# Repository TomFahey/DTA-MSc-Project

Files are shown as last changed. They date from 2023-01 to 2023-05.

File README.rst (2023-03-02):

DIY DTA
=======

Description
-----------

This project contains the assorted code and schematics used in the design of a low-cost Differential Thermal Analysis device. This design utilises off-the-shelf parts, in
conjunction with open source software, to provide a kit-based setup allowing users to explore basic application of the DTA technique, in an intuitive and low-cost manner.

Components
----------

The parts used in this design include:

* Raspberry Pi 4 Model B, running RaspbianOS (Buster)
* Raspberrry Pi Pico microcontroller
* Adafruit MAX31865 and MAX31856 temperature sensing breakout boards
* T-type thermocouple
* RTD sensors
* Cytron HAT-MDD10 motor controller board
* Adjustable DC Power Supply
* Custom PCB boards

Structure
---------

The repository consists of three main parts:

1. The webapp folder contains the python code and .ipynb notebooks which implement the widget-based user interface. This is intended to be run on a small board computer (SBC), such as a Raspberry Pi Model B (preferably running Raspbian OS), using the JupyterLab web-based interactive development environment. voila-dashboard, is used as a server extension within Jupyter, for deployment as a standalone web application.
2. The microcontroller folder contains the python code to be run on a CircuitPython compatible microcontroller (Raspberry Pi Pico), which interfaces with the SBC via USB.
3. The pcb folder contains the Autodesk Eagle files for the PCBs used by the system.

Documentation
-------------

The documentation for this project is available at `DIY-DTA <https://tomfahey.github.io/DTA-MSc-Project/>`_

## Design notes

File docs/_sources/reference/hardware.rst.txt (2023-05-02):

Hardware reference
==================

.. _ref_hardware_overview:

Overview
--------

A top-down overview of the system, indicating the respective roles of the 
components, is shown below:

.. figure:: ../images/HardwareDetailView.png
   :align: center
   :scale: 50%
   :alt: Microcontroller software block diagram

The *left* side of the diagram shows the components associated with high-level
system functions, such as:

* Displaying information and receiving user input 
* Defining heating programmes, based on user input and initiating/stopping
  these based on user commands
* Communicating with the microcontroller program, updating it with the 
  appropriate programed parameters and receiving sensor data sent by it.

The *right* side of the diagram shows the components associated with the low-level 
integration of electronics components and control processes, such as:

* Reading values from attached temperature sensors
* Regulating heat output of the thermoelectric module, based on parameters specified
  by the current heating programme, as well as the current temperature readings
* Communicating with the web app program running on the Raspberry Pi, sending
  temperature data as requested and receiving parameters related to the heating
  programme.

.. _ref_hardware_electronics:

Electronics
-----------

.. _ref_hardware_electronics_sensors:

Temperature Sensors
^^^^^^^^^^^^^^^^^^^

As previously shown in :doc:`components`, the temperature sensors that can be
used with the system include restistance temperature detectors (RTDs) or
thermocouples.

For absolute temperature measurements, the details of how RTDs and thermocouples
function, and their differences are not particularly important. In general, RTDs
will achieve greater precision, up to 0.1 degrees Celsius, compared to
thermocouples, which are typically limited to approximately 0.5 degrees Celsius
precision - however, these will be subject to the specific type of RTD/thermocouple
used.

However, in the case of differential temperature measurements, thermocouple
temperature sensors are able to provide a unique advantage over RTDs, due to
their ability to be wired in a 'differential' setup, as shown below:

.. figure:: ../images/DifferentialThermocouple.png
   :align: center
   :scale: 60%
   :alt: Thermocouple wiring

The voltage produced at the open terminals of the differentially wired thermocouple
is approximately proportional [#T-Type]_ to the difference in temperature between
the two probes [#Non-linearity]_ . For sufficiently high-resolution voltage sensors,
this can allow a differential thermocouple to achieve precision in the tens of
mK. 

Because the temperature-dependent voltage values produced by the sensors is typically
very small (in the mV, or less), the use of amplification, or high-resolution voltage
sensors (or both) is necessary to extract the temperature readings.

Unsurprisingly, integrated chips providing exactly these features are available, such
as Analog's MAX31865 (RTD) and MAX31856 (Thermocouple) products. These ICs both feature
high-resolution ADCs, precision voltage/current references, built-in amplification and
SPI communication, allowing them to be easily integrated with a microcontroller over
the SPI bus. 

The Adafruit breakout boards used for the system integrate these ICs, allowing any 
combination of up to 4 RTDs/Thermocouples to be used for temperature measurements.

.. _ref_hardware_electronics_actuators:

Temperature Actuators
^^^^^^^^^^^^^^^^^^^^^

The temperature control of the sample and reference is handled with the use of
a thermoelectric module (TEM). This is a type of solid state device, which acts 
like a heat pump, in response to an applied electrical current - heating on one
side, whilst cooling on the other. 

This heat pump effect can be reversed by reversing the direction of the electric 
curent, causing the previously heated side to cool and vice versa. This allows
TEMs to achieve very precise temperature control, by applying corrective
heating/cooling to an attached object, in order to maintain a target temperature.

In order to apply the reversible current needed to drive the TEM, an electronic
circuit called a H-Bridge is used, consisting of four switching transistors,
which selectively allow current to flow in one direction, or the opposing one,
based on the input applied to their control terminals (e.g voltage applied
to the gate terminal, in the case of MOSFET transistors).

.. figure:: ../images/HBridge.png
   :align: center
   :scale: 25%
   :alt: H Bridge
   
This type of circuit is often used to drive reversible electronic loads, such 
as brushless DC motors, or speakers - typically with the use of a pulse-width
modulated (PWM) signal to control the switching of the MOSFETs. These very
common usecases mean that existing implementations of H-Bridge circuits are
both plentiful and relatively cheap, allowing off-the-shelf parts, like the
HAT MDD10A to be used for our purposes.
   
Additional care is needed in the case of TEMs when it comes to PWM control,
however, due to issues such as thermal cylcing [#TE-Tech]_ and reduced
efficiency [#THERMICOOL]_ . For these reasons, a low-pass LC filter is used,
as shown below, to smooth the PWM output of the H-Bridge, which is present
on the 
:ref:`Thermoelectric module interface board <_start_components_custom_tem_board>`.

.. figure:: ../images/ClassDAmp.png
   :align: center
   :scale: 25%
   :alt: Class D Amplifier

.. rubric:: Footnotes

.. [#T-Type] `NIST Temperature-Voltage chart for T-type thermocouple
      <https://srdata.nist.gov/its90/download/type_t.tab>`_
.. [#Non-linearity] In practice, the non-linearity in the temperature-voltage
      relationship is accounted for either by use of the Callendar-Van Dusen
      equation, or interpolation of a lookup table.
.. [#TE-TECH] `TE-Tech Technical Information <https://tetech.com/faqs/#11>`_
.. [#THERMICOOL] `Active Thermoelectric Cooling Solutions for Airspace 
      Applications: the THERMICOOL Project
      <https://ieeexplore.ieee.org/stamp/stamp.jsp?tp=&arnumber=7862124>`_

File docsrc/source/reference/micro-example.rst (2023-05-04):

Microcontroller software example
================================

.. role:: pyc(code)
   :language: python
   :class: highlight

.. _ref_micro_example:

This document describes a stripped-down version of the python code developed
for the DTA system, intended to provide a more easy to follow demonstration
of the underlying processes going on in the full implementation.

The stripped-down version of the code is (mostly) contained within a single file,
main.py, which carries out an approximately equivalent routine to the
full microcontroller code, without the use of programming abstractions
such as separate classes and modules. 

Requirements
------------

In order to properly familiarise yourself with the effects of each
part of the code you will need the following items:

- A Raspberry Pi Pico, with headers attached, running CircuitPython (7.3.3,
  preferably). Instructions on how to install CircuitPython 
  `here <https://learn.adafruit.com/welcome-to-circuitpython/installing-circuitpython>`_.
- A Windows or Linux computer, with the Python editor 
  `Thonny <https://thonny.org/>`_  installed. Also needed is a serial client
  application. `PuTTY <https://www.putty.org/>`_, available on both Windows
  and Linux, is an excellent choice for this and is the client used in this
  tutorial. 
- A Micro USB cable to attach the Pico to the computer
- At least one `Adafruit MAX31865 RTD amplifier <https://www.adafruit.com/product/3328>`_ 
  breakout board and an accompanying RTD temperature sensor
- At least one `Adafruit MAX31856 Thermocouple amplifier <https://www.adafruit.com/product/3263>`_ 
  breakout board and an accompanying thermocouple temperature sensor
- For proper demonstration of temperature control, a thermoelectric module
  (TEM), DC power supply and 
  `HAT-MDD10A <https://www.cytron.io/p-10amp-6v-24v-dc-motor-driver-hat-for-rpi-2-channels>`_ 
  H-Bridge motor controller are strongly recommended. 
- It is feasible to substitute the H-Bridge controller with an appropriately 
  spec'd high-side or low-side logic-level MOSFET (such as the FQP30N06L)
  using the PWM output of the MCU to control the MOSFET's gate terminal.
  However, if doing so, you **must** edit lines 435 and 437, making sure to
  set the value of both PWM pin's duty cycle to zero, when :pyc:`u<0`.
- Wires and preferably a small breadboard to connect everything

Hardware setup
--------------

With all of the necessary parts obtained, you will need to
connect the electronics according to the following diagram:

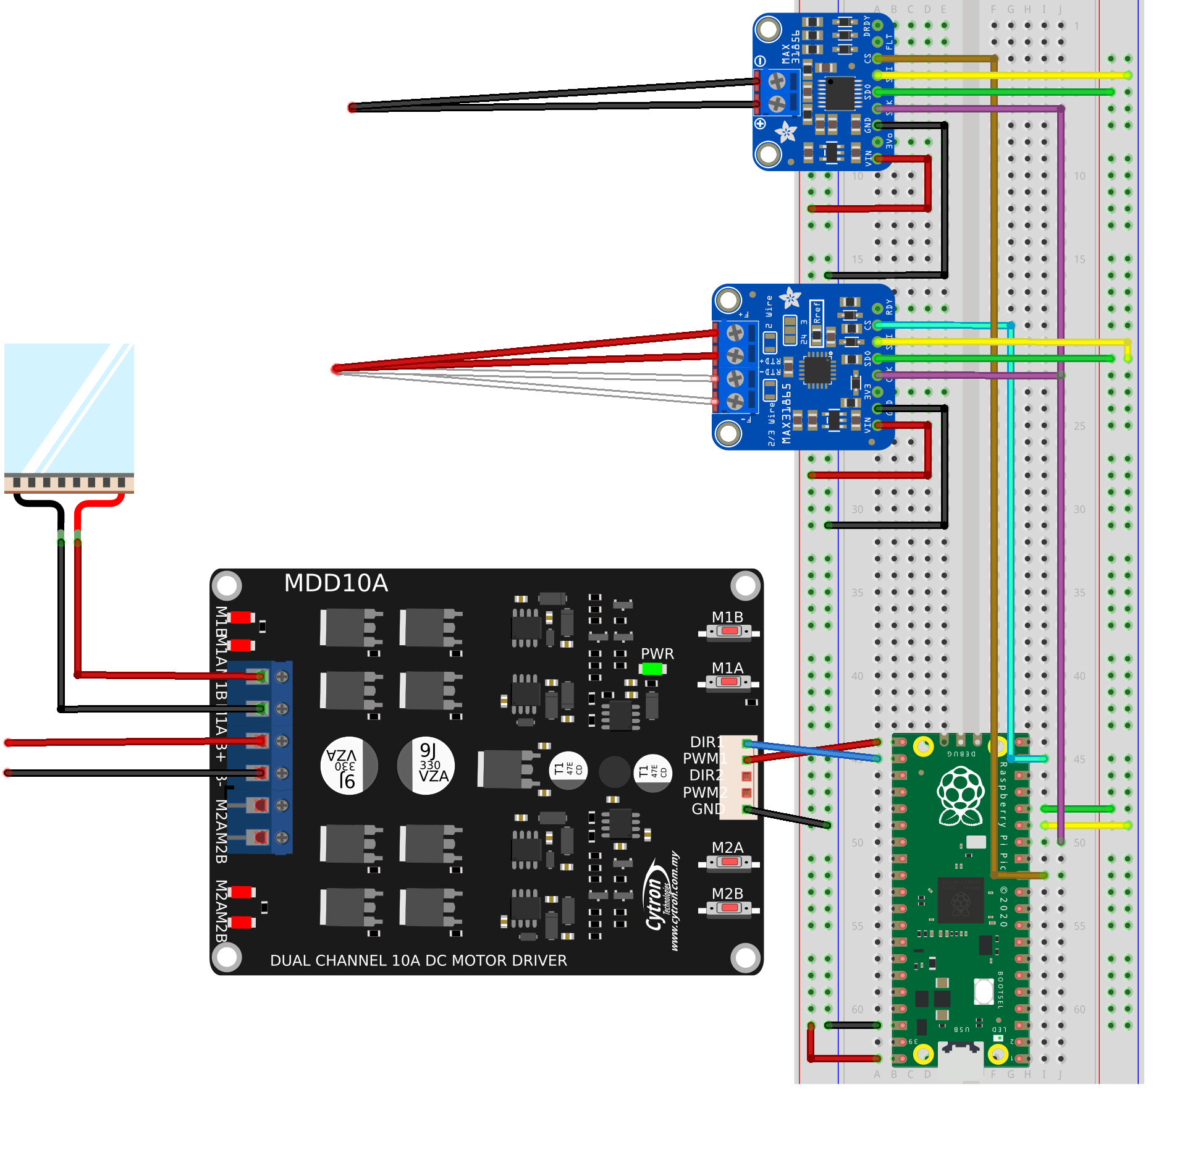
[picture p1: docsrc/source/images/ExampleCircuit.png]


The unconnected red and black wires on the left-hand side of the diagram
should be connected to the positive and negative connections of the DC
power supply, respectively.

For the purposes of demonstrating temperature and heat control, the
thermocouple and RTD sensors can simply be attached directly to one of
the faces of the thermoelectric module. We will want to attach it to the
side that gets hot (the other side will cool down), which depends on the
direction of the current that drives it.

You can test this yourself, by using the buttons marked M1B and M1A. These
buttons allow the H-Bridge to be manually controlled, with one button
providing forward current and the other reverse current.

Pressing down M1A, you should find that one side of the TEM heats up, whilst
the other side cools down. With M1B pressed down instead, you should find
the sides are now reversed i.e the previously hot side is now cold and the
previously cold side now hot etc.

For the MAX31865 amplifier board, you may need to short some of the solder
bridges arranged on the board, depending on the number of wires used for
your RTD sensor. You can find more information about this in the Adafruit
`online instructions <https://learn.adafruit.com/adafruit-max31865-rtd-pt100-amplifier/rtd-wiring-config>`_.

Software setup
--------------

With Thonny and a suitable serial communication application installed, you
should open Thonny up, which should look somewhat similar to the picture below:

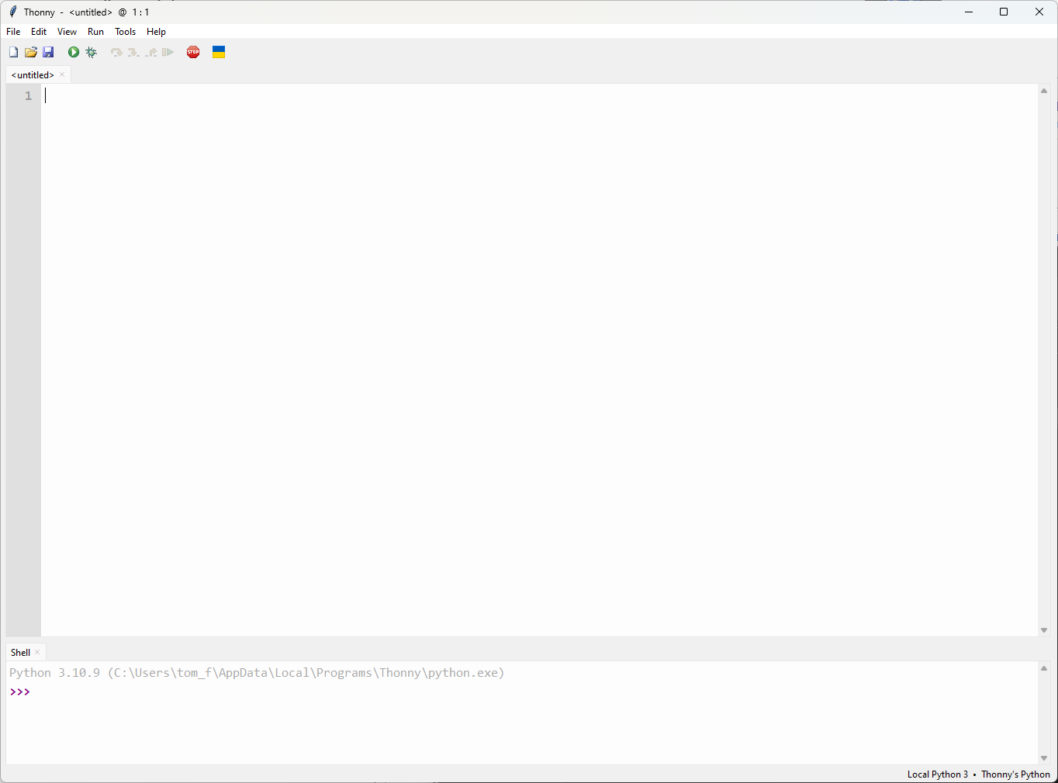
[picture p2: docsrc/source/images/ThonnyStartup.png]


We can see in the bottom right hand corner that the current *interpreter* is
configured to the local Python 3 installation on the computer. We therefore
need to change this to the CircuitPython interpreter, that is on the Pico.
With the Pico plugged into the computer via the USB connection, left-clicking
the interpreter in the bottom right-hand corner should result in the following
menu, from which you should select CircuitPython:

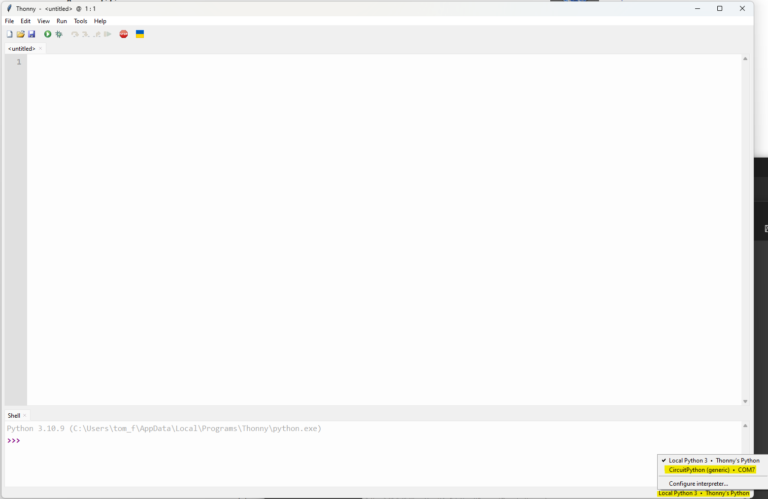
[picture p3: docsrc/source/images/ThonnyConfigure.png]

   
Next, we will want to configure the user interface, to show the necessary
elements. You can do this by clicking the "View" menu, making sure that the
highlighted options are selected:

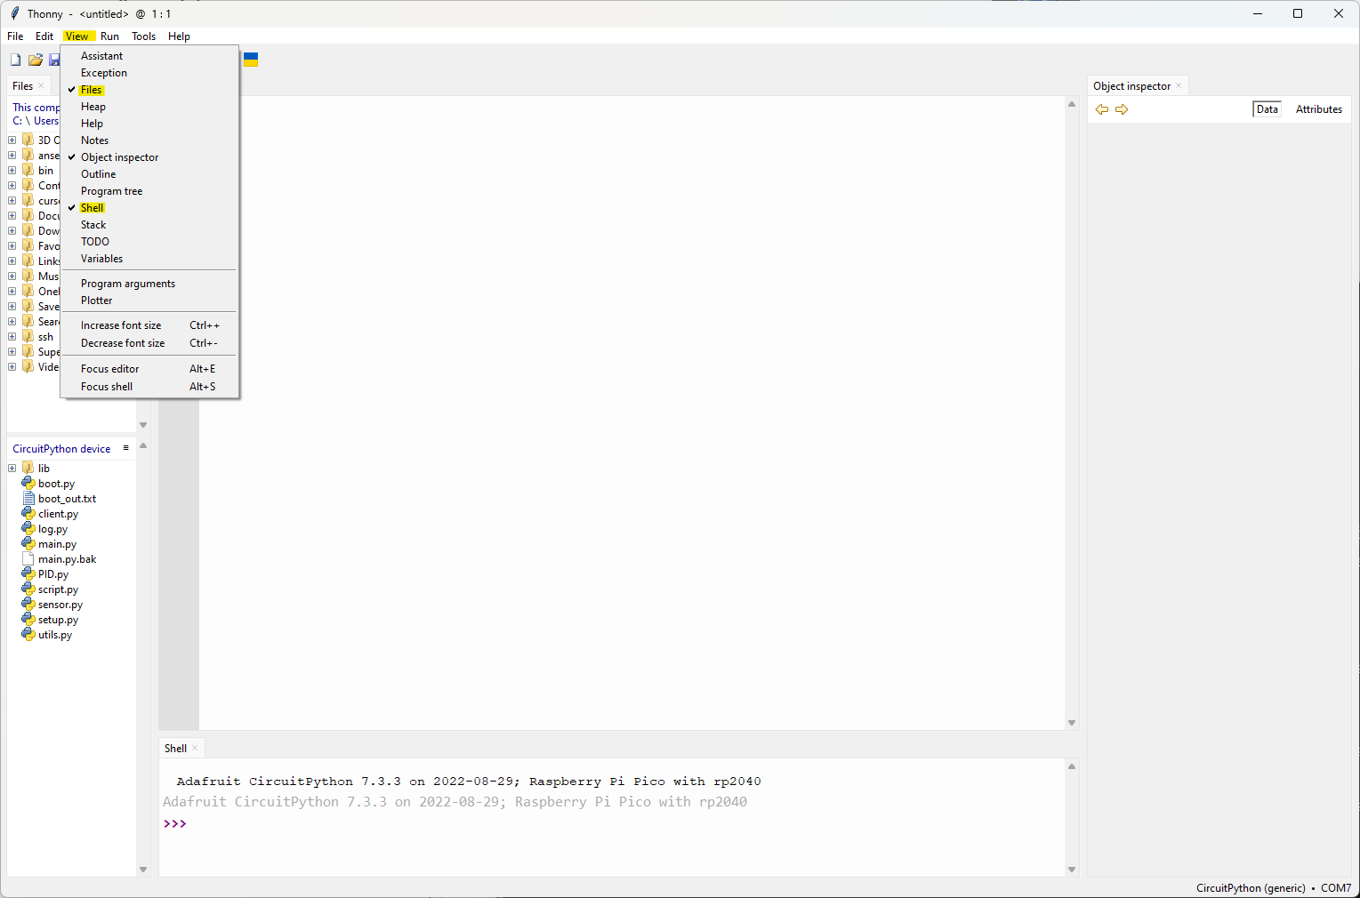
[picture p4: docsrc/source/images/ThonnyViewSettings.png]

   
You will probably notice that the Files menu shows two filesystems, namely
that of the local computer, as well as that of the microcontroller. In order
to install the python code used for this example, you will need to navigate
to where the files are stored on your own computer, from which you should
be able to copy them to the microcontroller by right-clicking on them as
shown below:

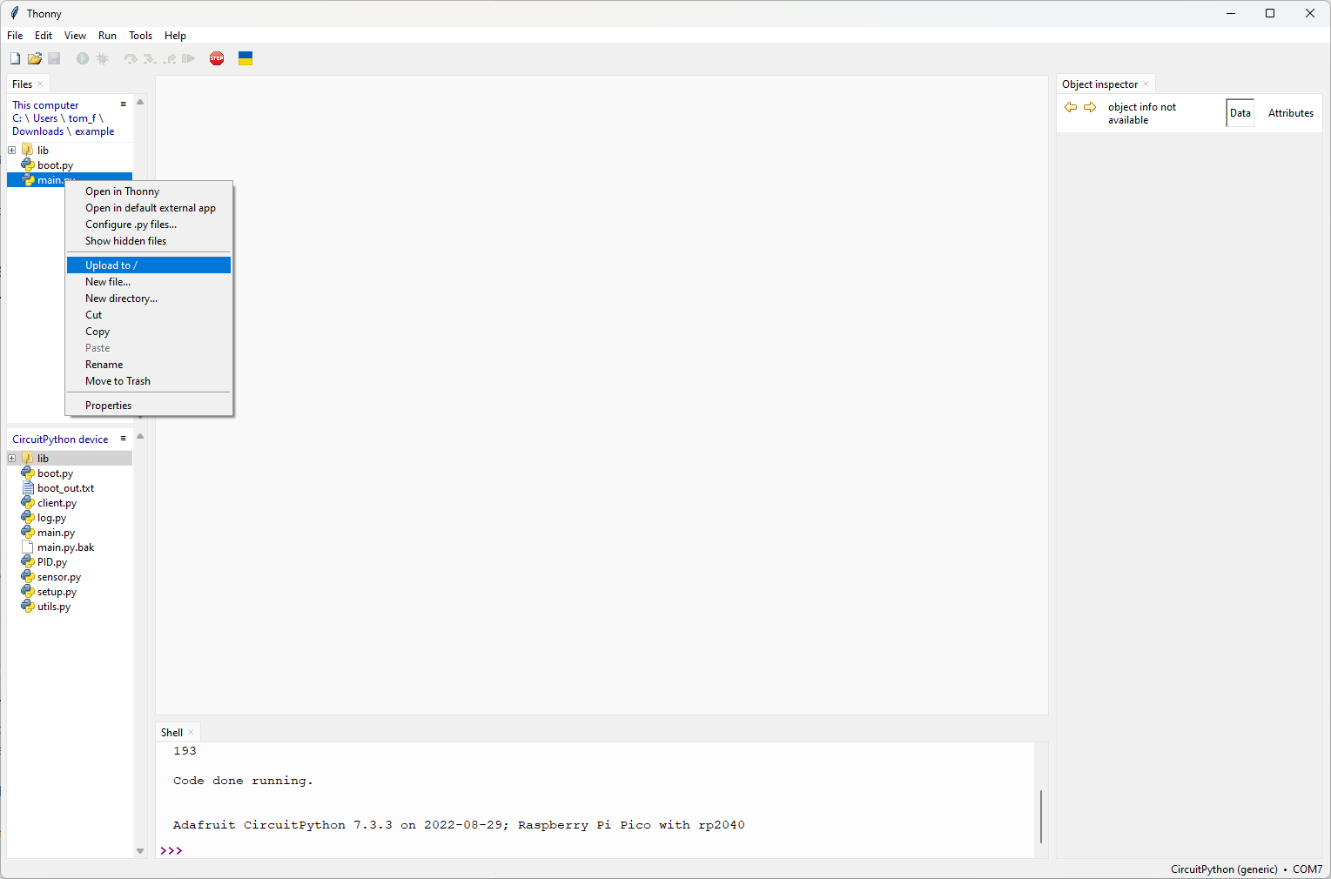
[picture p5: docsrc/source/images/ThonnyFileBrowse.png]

   
With the main.py and boot.py files, as well as the lib directory, copied to 
the Pico's filesystem, you can open the version of main.py installed on the
Pico by double clicking it.
   
Inspecting the program
----------------------

Upon opening main.py, you should see an approximately 450 line python
program, which has been divided into headered sections by the inline
comments.

The first 140 lines of code largely consist of boiler-plate code, such as
pin definitions, module imports and setting up periperhal devices.

Lines 10-13 import the basic interal Circuitpython libraries that are
required for measuring time, accessing board peripherals (like GPIO pins)
and buses such as the I2C, I2S, SPI, UART buses etc.

Lines 24-100 involve the initialising of the SPI devices, which in this
case, are the MAX31865 and '56 breakout boards. If you lookup a pinout
of the Pico, you will see that the pin definitions specified in lines 33-35
match the pins used in the wiring diagram shown earlier.

Between lines 52 to 100, the python objects used to model the two breakout boards
are initalised, :pyc:`max31865` and :pyc:`max31856`.

Temperature sensors
###################

We can get a better understanding of these objects by running the program and
inspecting them in the object inspector. Press the green "Run" button, to
run main.py and then type :pyc:`max31865` in shell prompt, hitting enter.

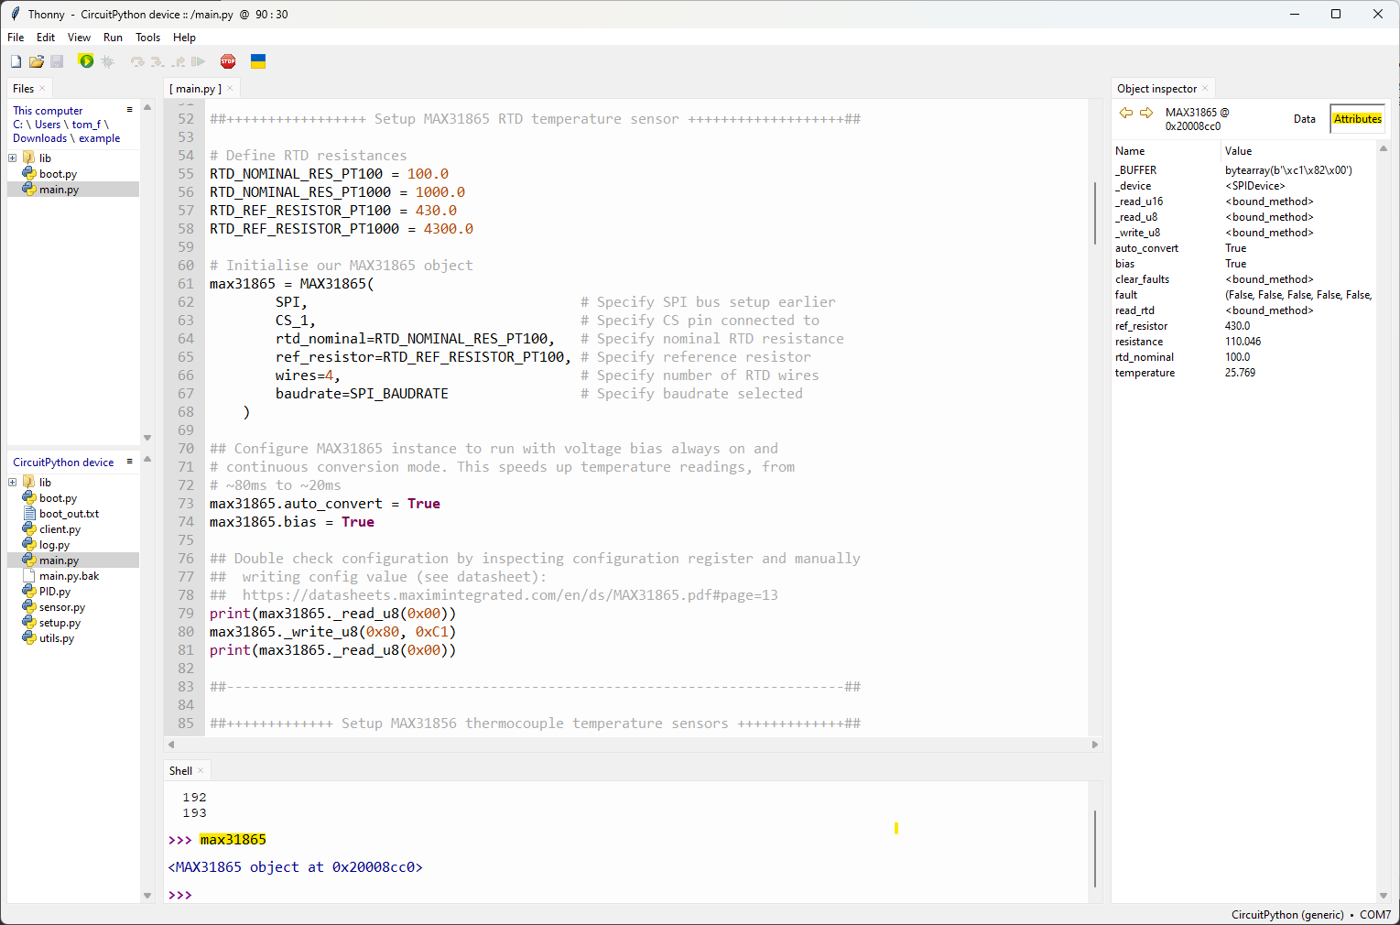
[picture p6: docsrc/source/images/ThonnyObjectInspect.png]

   
You should notice a new object appear in the Object inspector view. Clicking
on the Attributes tab will display the class features of the :pyc:`max31865`
object, including its attributes and methods. You will probably notice that
the value of some attributes, such as :pyc:`ref_resistor` and :pyc:`rtd_nominal` 
match those specified in the object's constructor.

Now try entering :pyc:`max31865.temperature` in the shell prompt and pressing
enter. This should return the current temperature detected by the board. You
should notice that when touching the RTD sensor, the temperature goes up.

PWM and DIR pins
################

Lines 115-136 involve the setup of the pulse-width modulation and logic output
pins, used to control the H-Bridge.

Once again, looking at the pin definitions, you will see that they match that
of the wiring schematic shown above.

Two pins are used to control a single thermoelectric module:

- The PWM pin controls the *amount* of current provided by the H-Bridge to the
  thermoelectric module. It does this by rapidly toggling on and off, at a
  relatively high frequency. The amount of time that the pin is LOW, relative
  to the amount of time that it is HIGH, determines the amount of current
  delivered - a value that is referred to as the *duty cycle*. For example,
  if the pin is high 70% of the time and low 30% of the time, it has a duty
  cycle of 70% and 70% of the maximum current will be provided to the TEM.
- The DIR pin controls the *direction* of the current flow through the TEM.
  When the DIR pin is HIGH, current will flow one way through the TEM; when
  it is LOW, the current will flow in the opposite direction.

Once again, you can test these ideas, by typing :pyc:`enPin1` into the
shell prompt. In the object inspector you should see a PWMOut object,
with a :pyc:`duty_cycle` attribute.

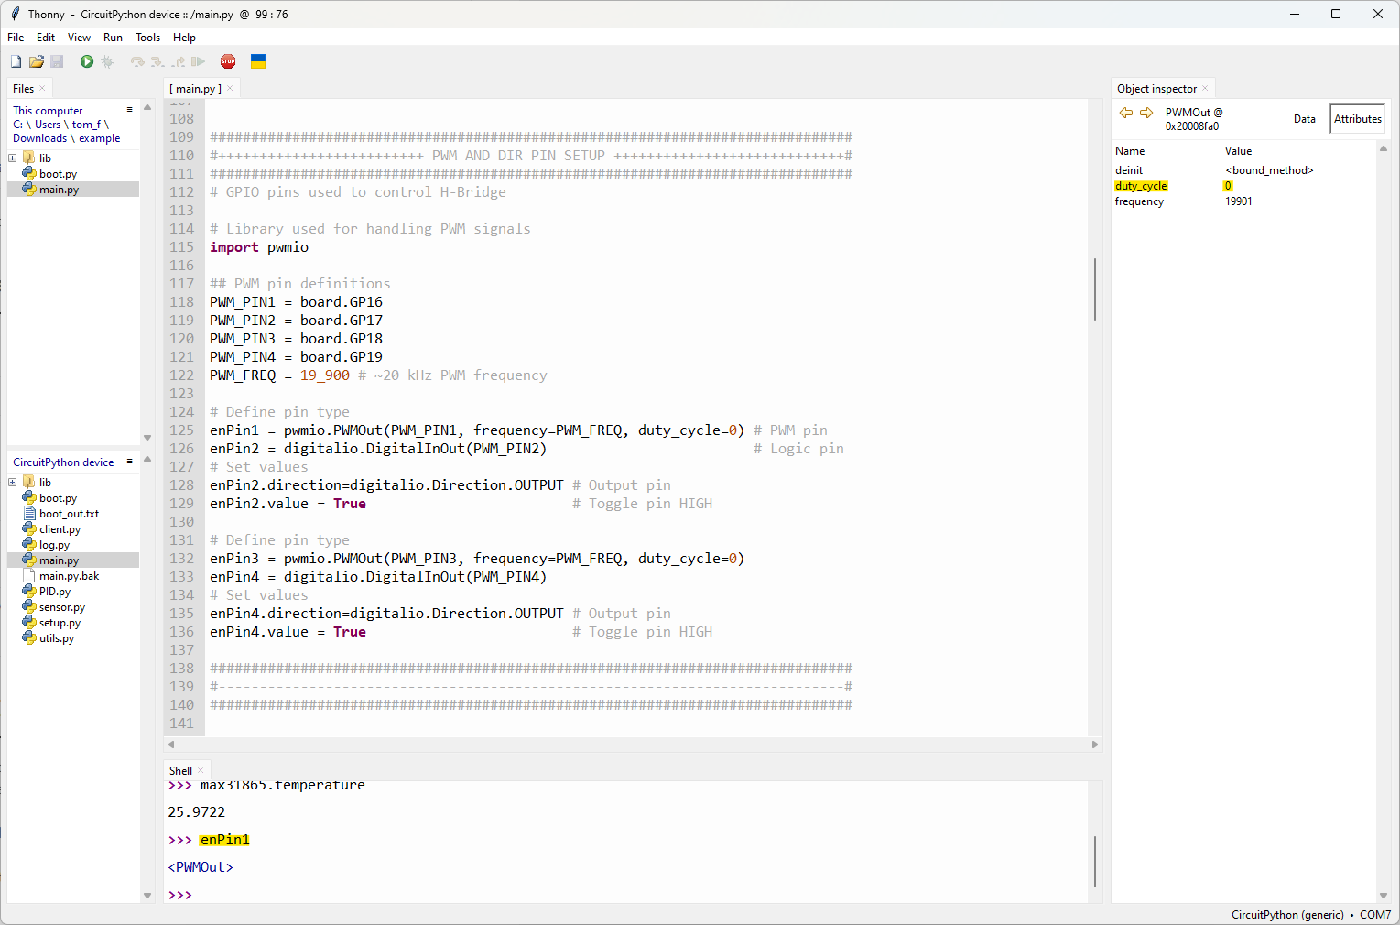
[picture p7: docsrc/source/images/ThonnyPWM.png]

   
Try changing this, by entering :pyc:`enPin1.duty_cycle = 16383` in the shell
prompt. Do you notice anything happening with the TEM? Now try modifying the
value of the direction pin, by entering :pyc:`enPin2.value = False`. Once again,
you should notice a change in the response of the TEM.

Serial communications
#####################

The reference `documentation <https://tomfahey.github.io/DTA-MSc-Project/reference/micro-software.html>`_ 
for the microcontroller software describes the background behind the
communication between the MCU and software running on the
Raspberry Pi. 

This communication is carried out over a *serial connection*, which is a
basic way for low-power devices to exchange information, typically in
the form of byte-encoded strings. 

The actual transport medium for the serial communication between the
MCU and Raspberry Pi in this case is the USB connection. The Rasperry Pi
Pico is capable of using a USB standard called USB-CDC, which allows it
to emulate a serial port on the connected computer, appearing as a virtual
COM port.

On Windows, this can be seen in the Device Manager, as entries under the
Ports (COM & LPT) heading, as in the picture below:

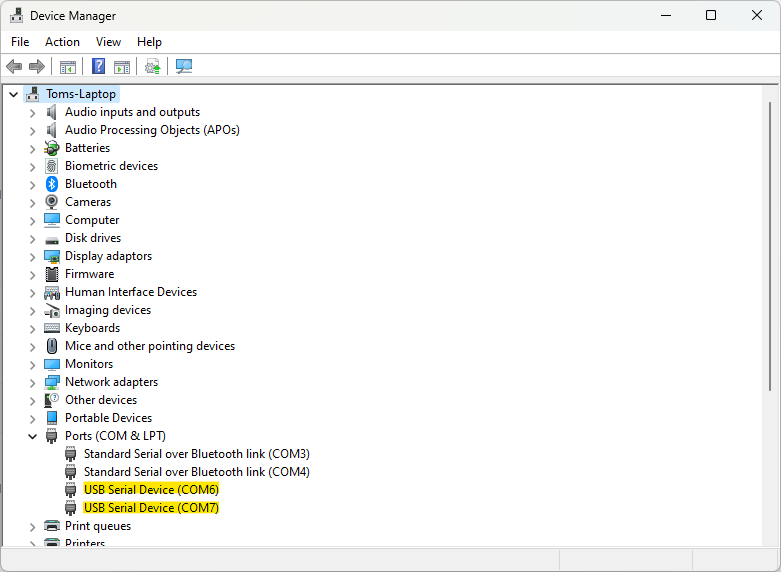
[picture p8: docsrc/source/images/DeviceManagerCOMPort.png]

   
We can see that two serial devices are listed, COM6 and COM7. Looing back
at the earlier figure, where we selected the CircuitPython interpreter, you
will notice that this was COM7. Indeed, in CircuitPython, normally only one
COM port would appear on the computer - the one associated with
the REPL shell that we've been using in Thonny.

If you open the file :pyc:`boot.py`, you will notice that it contains an
import statement for the CircuitPython :pyc:`usb_cdc` library, as well as
a function call featuring that library, on line 9. Inside the function
argument, both of the parameters, :pyc:`console` and :pyc:`data` are set
as :pyc:`True`. By default, only the former is normally enabled, providing
the REPL prompt. By enabling :pyc:`data`, we get an extra serial channel,
which can be used to pass messages from the computer to the Pico and vice
versa.

Let's try this this out. If you haven't already, press the red "STOP"
button in the Thonny interface to restart the Pico. This is necessary
because the :pyc:`boot.py` file is a special python file, that is
executed when the Pico initially boots. Therefore, even if you've copied
it to the Pico's filesystem, until the Pico reboots, it won't have any
effect. Upon rebooting, press the green "Run" button again to execute
:pyc:`main.py`

You should now see two USB serial devices listed in Device Manager under
different COM ports, where one matches that used by the interpreter in
Thonny and the other does not.

Now open the application PuTTY. You should see something like the following:

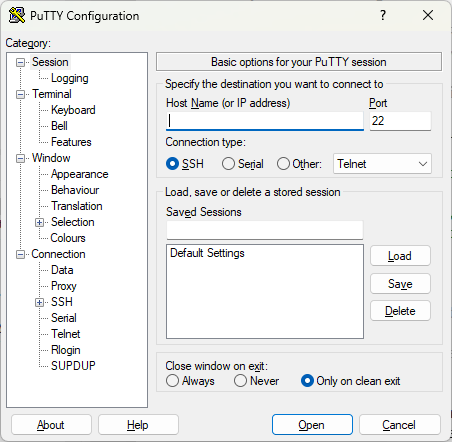
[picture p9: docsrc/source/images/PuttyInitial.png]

   
Change the connection type to Serial, entering the COM port that isn't
being used for the REPL interpreter and setting the "Speed" value to
115200:

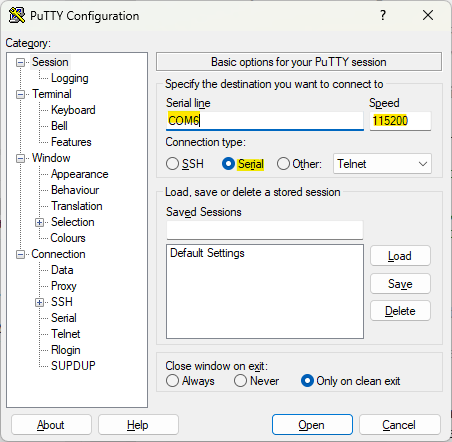
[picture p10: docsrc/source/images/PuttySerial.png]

   
Now press "Open". You should see a black window appear similar to the
following:

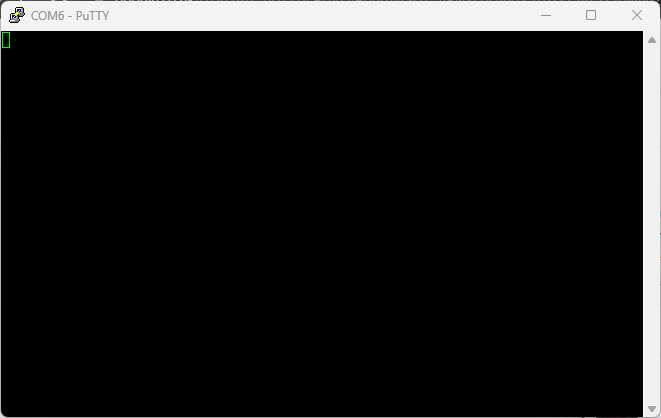
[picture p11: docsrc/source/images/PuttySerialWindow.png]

   
Going back to Thonny, enter the following code in the interpreter shell:

.. code-block:: python
   
   >>> serial.write(b'Hello, World!\n')
   
Looking in the PuTTY window, you should notice that the following text
is now present:

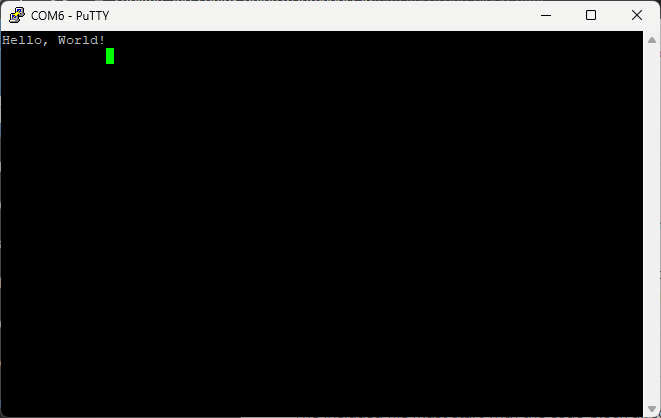
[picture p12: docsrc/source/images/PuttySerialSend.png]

   
Now, right click the top of the PuTTY window
and select "Change Settings". Select the category "Terminal", then set
the options "Local echo" and "Local line editing" to "Force on", before
clicking "Apply":

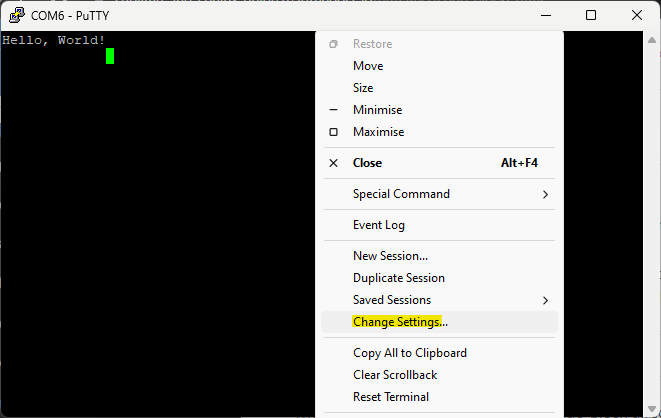
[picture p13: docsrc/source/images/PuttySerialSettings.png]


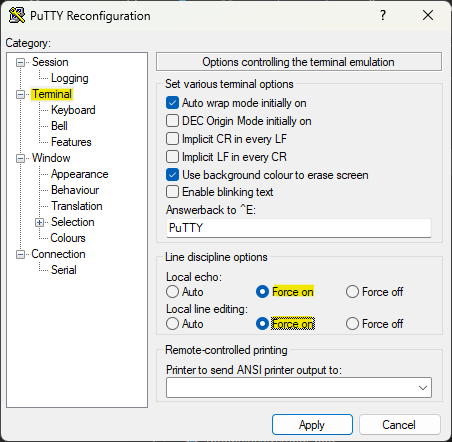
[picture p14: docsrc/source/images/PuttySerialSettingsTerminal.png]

   
Now, try typing "Goodbye, World!" into the **PuTTY** window, then press
Enter on your keyboard:

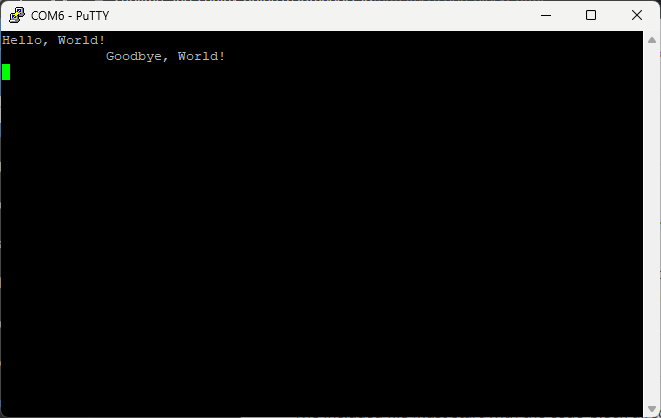
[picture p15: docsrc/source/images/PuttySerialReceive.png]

   
Going back to Thonny, now type into the REPL prompt:

.. code-block:: python
   
   >>> serial.readline()

You should see the following message:

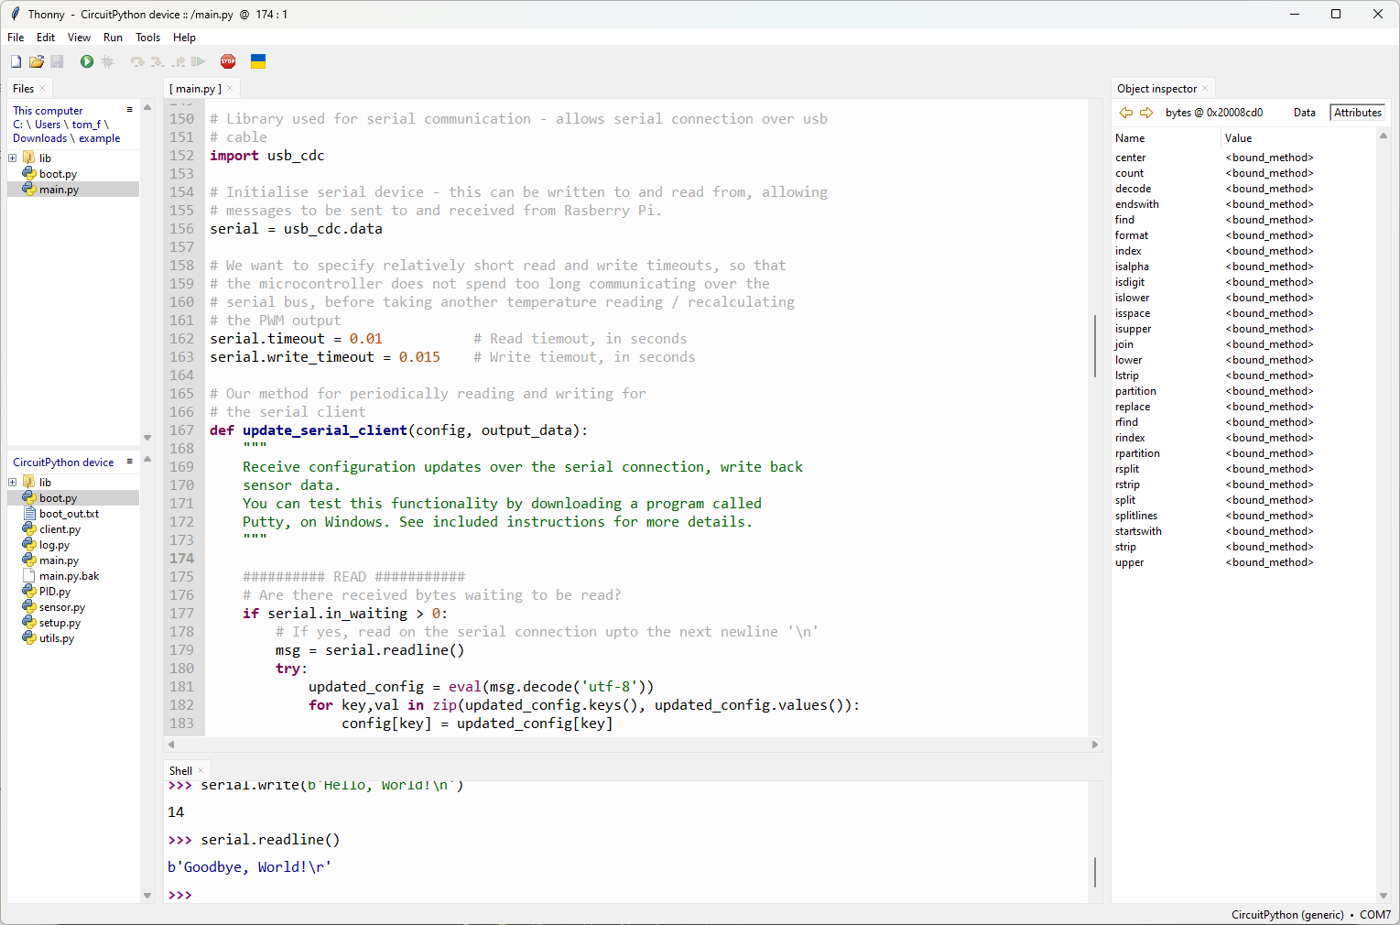
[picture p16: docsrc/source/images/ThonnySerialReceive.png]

   
Putting it all together
-----------------------

By now, you've basically seen all of the core library functions used to
control the the MCU, when it interacts with the other system components,
such as the temperature sensors, H-Bridge and Raspberry Pi. 

The remainder of the code, from line 167 onwards, simply utilises these
library functions in an organised manner, such that the individual, simple 
interactions come together to achieve more sophisticated behaviour.

To demonstrate this, try calling the function :pyc:`main.py`, in the REPL
prompt:

.. code-block:: python

   >>> main()
   
You should see a stream of messages printing out to the REPL shell, similar
to the following:

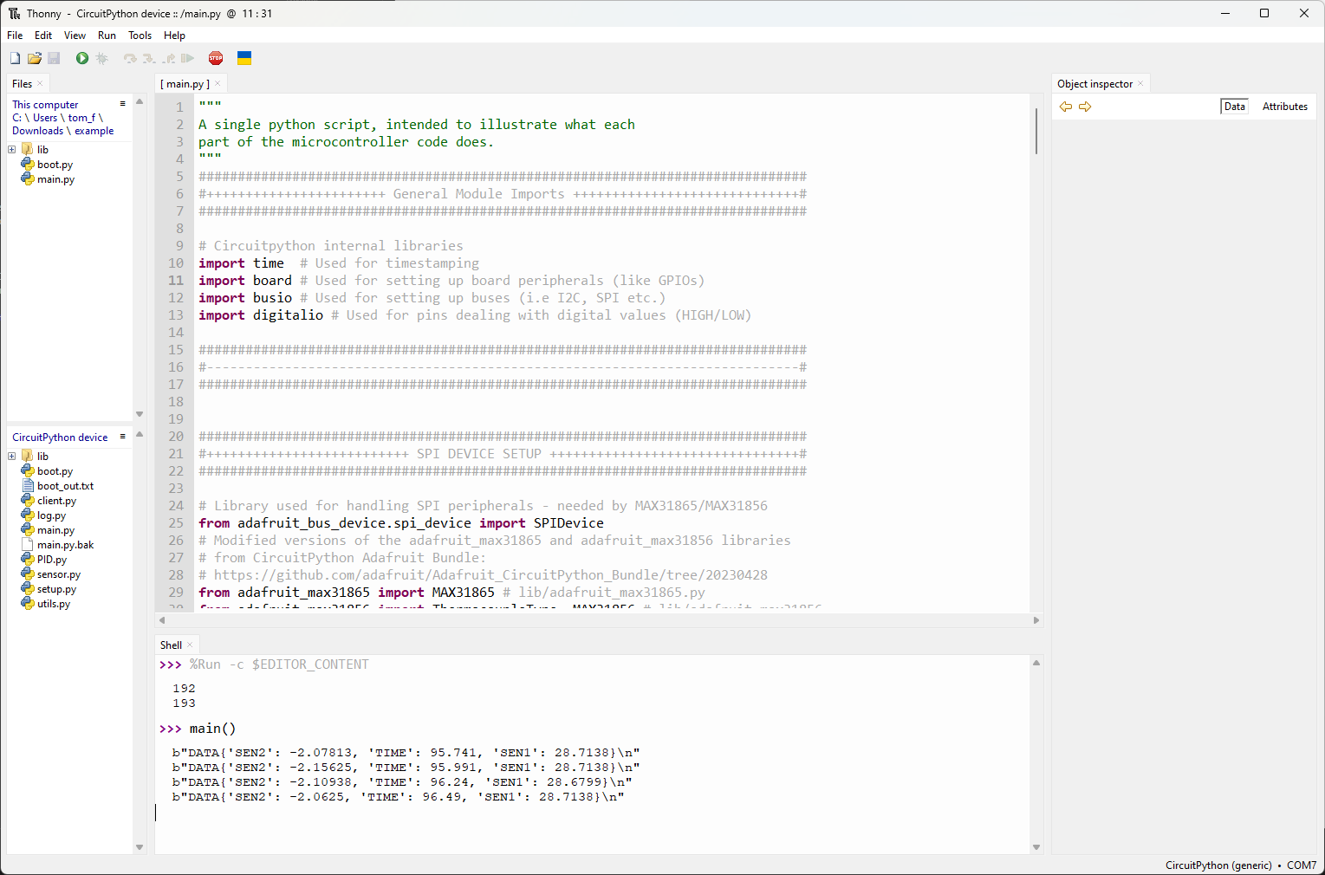
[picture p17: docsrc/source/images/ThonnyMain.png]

   
Can you notice anything about the timestamps - in particular, the time
difference between each one?

Try looking at the function definition of :pyc:`main.py`, in lines 383-392.
In the function argument, a default argument is specified, consisting
of a python dictionary called :pyc:`config`:

.. code-block:: python
   :lineno-start: 383

   def main(
      config={
        'RUN'       : False,  # Start heating run
        'MODE'      : False,  # Switch between heat ramp / temperature hold
        'LOG'       : False,  # Start time-stamping
        'TARGET'    : 23,     # Target heat rate / hold temperature
        'KP'        : 35.0,   # PID proportional gain constant
        'KD'        : 2.0,    # PID derivative gain constant
        'KI'        : 3.5,    # PID integral gain constant
        'INTERVAL'  : 0.25    # Time interval between readings
   )
   
Can you see anything interesting about the dictionary element :pyc:`'INTERVAL'`?
Now, going back to the PuTTY window, try typing in the following

.. code-block:: python

   {'INTERVAL':2}

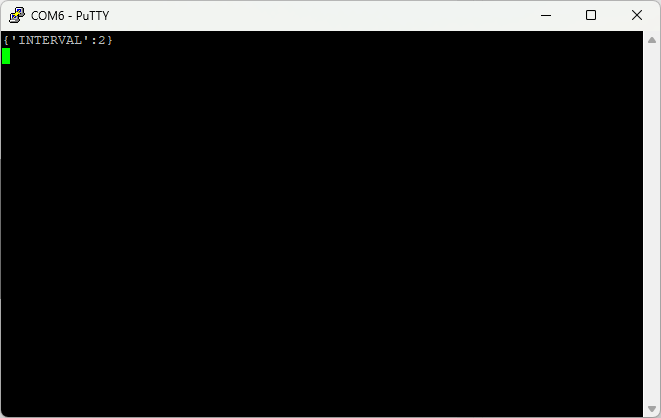
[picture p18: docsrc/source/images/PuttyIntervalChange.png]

   
and hit Return on your keyboard. What do you notice now about the messages
printing to the REPL?

You might want to try entering different commands in the Putty window -
however you should take care whenever enabling any options that will
result in the TEM heating up:

The config value :pyc:`'MODE'` specifies whether the PID control loop will
attempt to maintain a constant temperature (in degrees Celsius) or a constant 
heat rate (in degrees Celsius per minute).

The config value :pyc:`'TARGET'` is used in **both** cases, to specify either
the set point temperature, or set point heat rate. Therefore, you will see 
a big difference in the TEM's response, depending on the value of :pyc:`'MODE'`,
when setting the value of :pyc:`'TARGET'` to say:

.. code-block:: python

   {'TARGET':55}

If the value of :pyc:`{'MODE:False'}`, the TEM should heat the hot side until
it detects that the attached temperature sensors have reached a temperature
of 55 degrees celsius, at which point it will attempt to maintain that
temperature.

However, if the value of :pyc:`{'MODE':True}`, the TEM will attempt to heat 
the hot side at a rate of 55 degrees Celsius per minute, which is almost a
degree per second. Not only will this result in dangerous temperatures for
contact with skin in less than a minute, but the microcontroller will
attempt to constantly maintain that heat rate, up to a 100% duty cycle. 

For DC power supplies with current supplies greater than 2 Amps, this can
lead to thermoelectrc modules heating up to 120-150 degrees Celsius before they
self-destruct, due to the internal solder melting.

Therefore, care should be taken when experimenting, and it would be a good
idea to not power the TEMs for longer than a couple minutes at most.

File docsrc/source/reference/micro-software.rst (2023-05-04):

Microcontroller software reference
==================================

.. _ref_micro_intro:

.. role:: pyc(code)
   :language: python
   :class: highlight

Introduction
------------

In line with the project aim to provide a python-based implementation
that is relevant to a wide audience, the software developed for the
microcontroller uses 
`CircuitPython <https://docs.circuitpython.org/en/latest/README.html>`_, 
a derivative of 
`MicroPython <https://docs.micropython.org/en/latest/>`_`.

The reason for adopting CircuitPython over MicroPython was its built-in support
for USB-CDC. This feature allows a microcontroller that is connected to a 
computer via USB to simultaneously provide serial communication between the
python code running on the microcontroller and computer, in addition to
mass storage, allowing the microcontroller's python code to be updated easily.

In combination with the MicroPython REPL prompt, this provides a very user
friendly, familiar environment for Python programmers to engage in microcontroller
programming.
  
.. _ref_micro_overview:

Overview
--------

The high-level behaviour of the microcontroller is shown in the following picture:

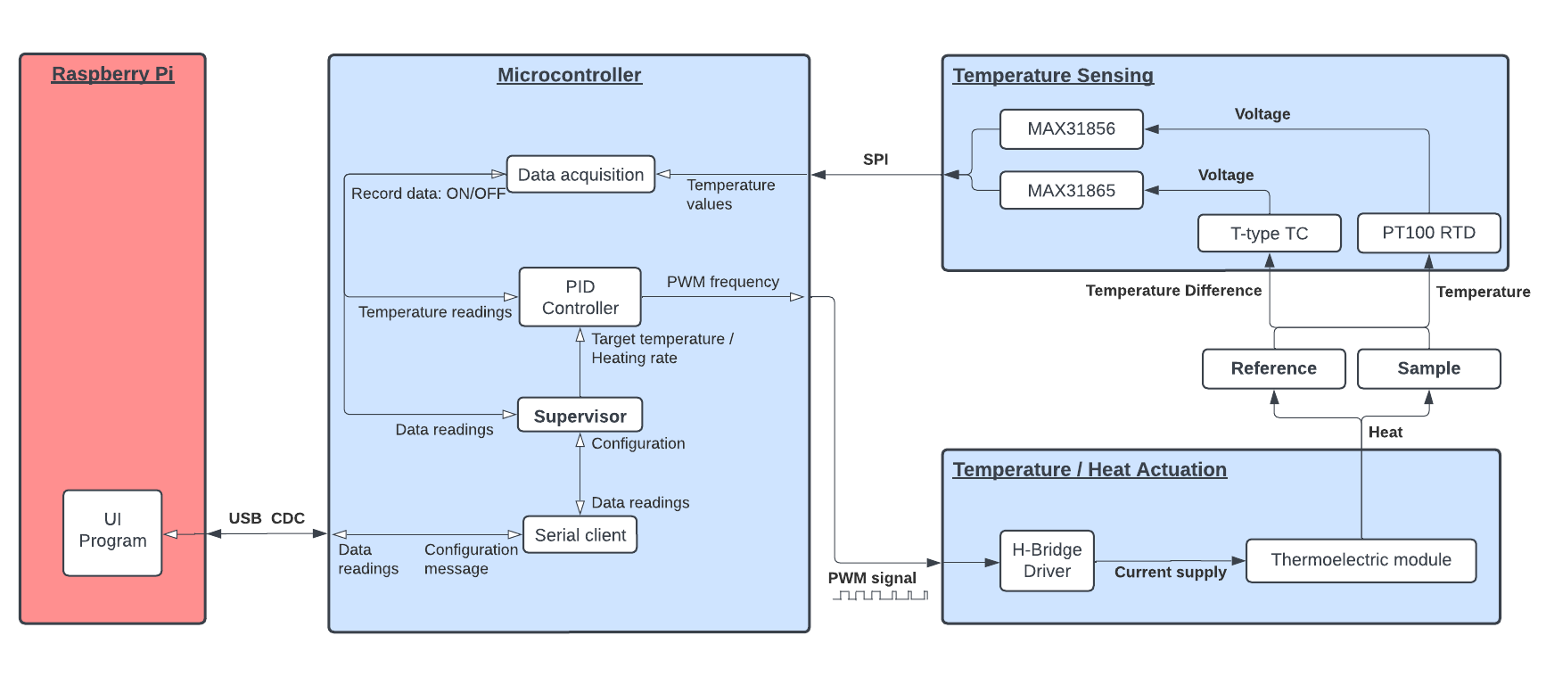
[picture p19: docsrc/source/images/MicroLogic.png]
Microcontroller logical block diagram


Components
##########
   
Focusing on the MCU, we can see that it is involved with three 
primary interactions:

- **Data aquisition**: The MCU interacts with the temperature sensing
  components, consisting of:
  
  - the physical temperature measuring sensors themselves (RTD/Thermocouple), 
    which are connected to 
  - the integrated chips (MAX31865/56) used to convert the voltages produced by the 
    sensors into digital temperature readings.
    
  The communication between the MCU and ICs is carried out over the SPI
  bus.

- **PID Control**: As described in the :ref:`ref_hardware_electronics_actuators`
  section, the heat output of the thermoelectric module is controlled by a
  H-Bridge electronic circuit. This H-Bridge driver takes two control input signals:
  
    - A PWM signal, controlling the *magnitude* of current supplied to the
      thermoelectric module (and thus *quantity* of heat pumped by
      the module), as well as 
    - A HIGH/LOW direction signal, controlling the *polarity* of the current
      as +ve or -ve (and therefore *direction* of heat pumping i.e cooling or
      heating)

  The MCU adjusts these two signals using a PID control loop,
  which takes into account the specified temperature or heat rate provided by
  the user and actual measured temperature or heat rate, adjusting the control
  signals so that the measured values move towards the target values.
  
- **Serial communication with Raspberry Pi**: Because control of the 
  system is done via the user interface program running on the Raspberry Pi,
  when a user carries out any command such as

    - specifying a target temperature or heat rate,
    - initiating/stopping a heating run,
    - modifying system parameters such as the PID gain,

  this information needs to be communicated from the Pi to the MCU.
  This is done via *"configuration messages"*, which are sent over a serial
  connection from the Pi to the MCU. The same connection is also used to
  send the temperature readings captured by the MCU back to the Pi, which are
  displayed on the temperature-time chart of the UI.

Supervisor
##########

In practice, the specific details of the interactions described above do not
stay fixed. Consider the following examples:

   - When the system is idle (i.e not carrying out a heating run), the PID
     controller's output should be switched off, to prevent the thermoelectric
     module from heating the sample and reference. The MCU should still capture
     temperature data, as the UI program running on the Pi will need to know the
     *starting temperature* for a heating run, however these temperature readings
     do not need to be timestamped and can be updated relatively infrequently.

   - When the system is active, the PID controller's output needs to be enabled.
     When capturing temperature data, the MCU must timestamp this, referenced to
     the time the heating run started, so that the heating rates can be verified
     later on.

   - As was discussed in the :ref:`usage_basic_ui_programme` section, heating
     runs consist of individual heating **stages**, which have two parts, a
     *heating ramp* and a *hold period*. The former consists of a constant *heat
     rate* temperature increase up to a *target temperature*, whilst the
     latter involves holding the temperature constant at the *target temperature*
     for a given *hold time*.

     The method used by the PID controller to determine the value of its
     output control signal will need to change, depending on whether it is
     controlling a heat ramp or hold period.

This variable behaviour explains the need for *configuration messages*,
passed from the Raspberry Pi to the MCU, which allow it to carry out the
correct behaviour that matches the state of the UI program.

These configuration messages are parsed by a **Supervisor**
on the MCU, which is responsible for keeping the microcontroller state
(or "configuration") in sync with that of the UI program on the
Raspberry Pi.
    
Program Structure:
------------------

The basic logical structure of the microcontroller python code is therefore 
illustrated below:

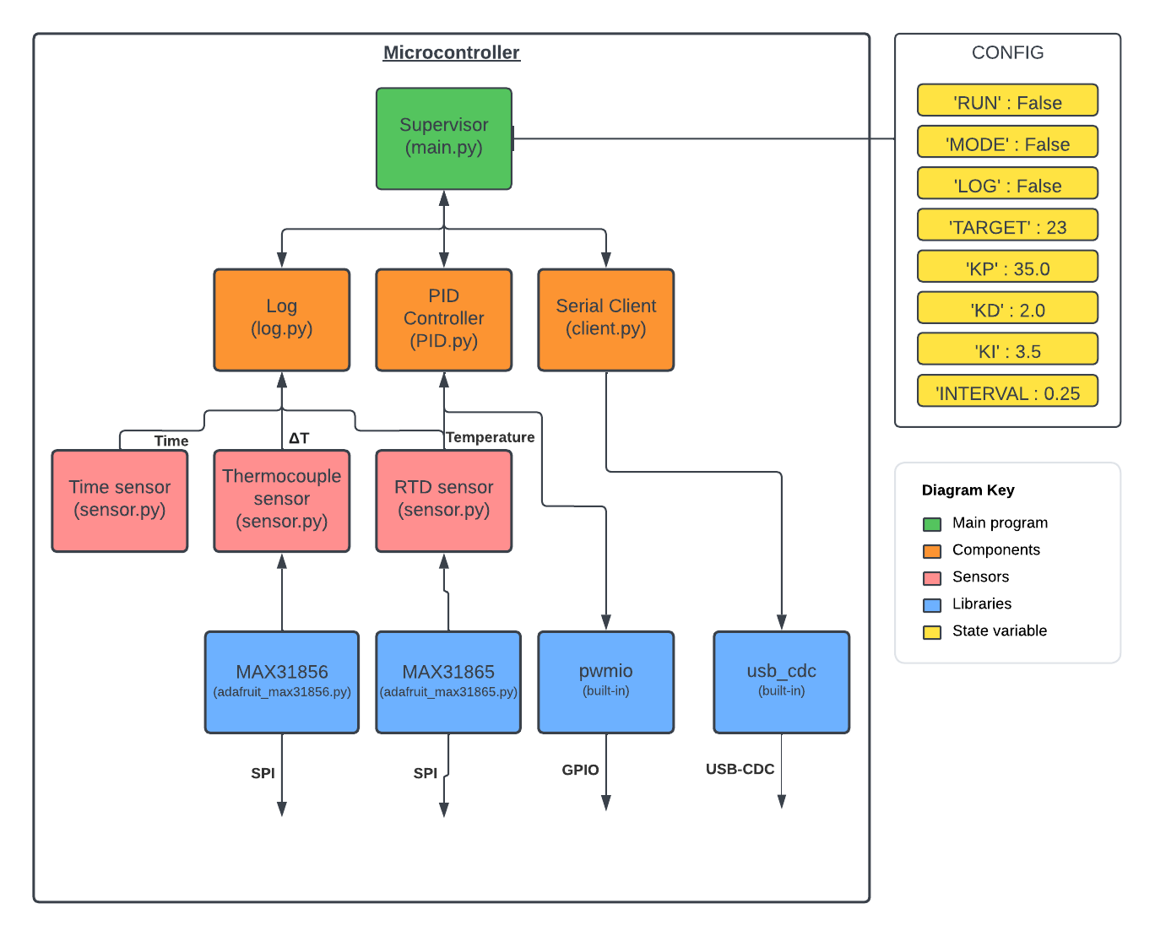
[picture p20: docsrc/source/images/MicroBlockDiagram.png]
Microcontroller software block diagram


Component classes
#################
   
Looking at the three (orange shaded) **Component** classes, the three 
interactions discussed above form the basis for three program
classes, with each class handling one of the interactions.

- **log** - handles logging of data, such as temperature values, time, etc.
- **PID** - handles temperature control, using a PID control loop
- **client** - handles serial communication with UI program running on the Raspberry Pi

All three classes adopt a similar interface, in the form of their **update()** methods,
which, when called, will handle the tasks detailed above. 

Supervisor classes
##################

The (green shaded) **Supervisor** class adopts the three component objects when it's created,
(:pyc:`main.py`)

.. code-block:: python
   :lineno-start: 28

   class Supervisor:
       """
       ...
       """
    def __init__(self, serial_client, PID, log):
        
        self.components = [serial_client, PID, log]
        self.client = serial_client

.. code-block:: python
   :lineno-start: 103

   thisSupervisor = Supervisor(thisClient, thisPid, thisLog)

calling their :pyc:`update()` methods, as part of its :pyc:`run()` routine.

.. code-block:: python
   :lineno-start: 83
   :emphasize-lines: 2

   def run(self):
       _ = [component.update() for component in self.components]
       self.pull_config()
       self.push_data()
        
The other two routines on lines 85 and 86 are used for the following:

- :pyc:`pull_config()` involves the :pyc:`Supervisor` instance reading any
  configuration messages sent to the MCU by the Pi and adjusting the
  corresponding :pyc:`config`` parameters for each of the three components
- :pyc:`push_data()` involves the :pyc:`Supervisor` 'popping' data from the
  :pyc:`Log` component and sending it to the Pi.

Sensor classes
##############

The class :pyc:`Sensor` basically functions as a wrapper class for the
different data readings that the MCU captures.

Wrapper classes essentially take existing programming classes and "wrap" them
in a common interface, so that the same functions can be called on all of them.

The :pyc:`Sensor` class simply provides a common :pyc:`read()` method, which
allows the :pyc:`Log` and :pyc:`PIDState` classes to treat data generating 
objects in the same manner:

.. code-block:: python
   :lineno-start: 30
   :emphasize-lines: 5,6

   class TempSensor(Sensor)

   ...

   def read(self):
      return round(self.device.temperature, self.precision)

.. code-block:: python
   :lineno-start: 40
   :emphasize-lines: 5,6

   class TimeSensor(Sensor)

   ...

   def read(self):
      return self.time
   
For example, when the :pyc:`Log` class - which takes :pyc:`Sensor` type objects
when its created, in much the same way the :pyc:`Supervisor` class takes
component classes - has its :pyc:`update()` method called, this is what happens
underneath:

.. code-block:: python
   :lineno-start: 73
   :emphasize-lines: 5,6

   def update(self):

   ...

   for nth_sensor in self.sensors:
      self.readings[nth_sensor].append(self.sensors[nth_sensor].read())

In summary, the :pyc:`Sensor` class basically just provides a modular way to
treat potential data sources such as temperature sensors, time-stamping etc.
This would be equally applicable for other potential data sources, such as
the MCU's ADC etc.

Configuration Messages
######################

As discussed above, configuration messages are passed from the Pi to the MCU
in order to change the behaviour of some of the component classes, in response
to the user's use of the system.

The actual format of the configuration messages is UTF-8 byte-encoded string
representations of Python dictionaries, where the following key:value pairs
can be used:

.. code-block:: python

   CONFIG = {
      'RUN'       : False, # Specifies system idle / active
      'MODE'      : False, # Specifies heat ramp / temp hold mode
      'LOG'       : False, # Initiates time-stamping when enabled
      'TARGET'    : 23,    # Target heat rate / target temperature
      'KP'        : 35.0,  # Proportional gain for PID control loop
      'KD'        : 2.0,   # Derivative gain for PID control loop
      'KI'        : 3.5,   # Integral gain for PID control loop
      'INTERVAL'  : 0.25   # Time interval between successive readings (s)
      }

API Reference:
--------------

Main program
^^^^^^^^^^^^

.. toctree::
   :maxdepth: 2

   micro/main

|

Component classes
^^^^^^^^^^^^^^^^^

.. toctree::
   :maxdepth: 2

   micro/client
   micro/log
   micro/PID

|

Wrapper classes 
^^^^^^^^^^^^^^^

.. toctree::
   :maxdepth: 2

   micro/sensor

|

Miscellaneous
^^^^^^^^^

.. toctree::
   :maxdepth: 2

   micro/boot
   micro/setup
   micro/utils

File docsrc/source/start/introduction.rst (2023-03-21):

Introduction
============

.. _start_intro_dta:

Differential Thermal Analysis
-----------------------------

Differential thermal analysis (DTA) is a thermal analysis technique that involves measuring
the difference in temperature between a material of interest (the *sample*) and an inert
reference material (the *reference*), as both are heated/cooled under identical, controlled conditions.

Materials, when heated, will undergo phase transitions at certain temperatures, that are characteristic of the given
material's underlying chemical structure. A common example of this is the melting point of ice, at 0°C, as well as
the boiling point of water, at 100°C, shown in the figure below [1]_:

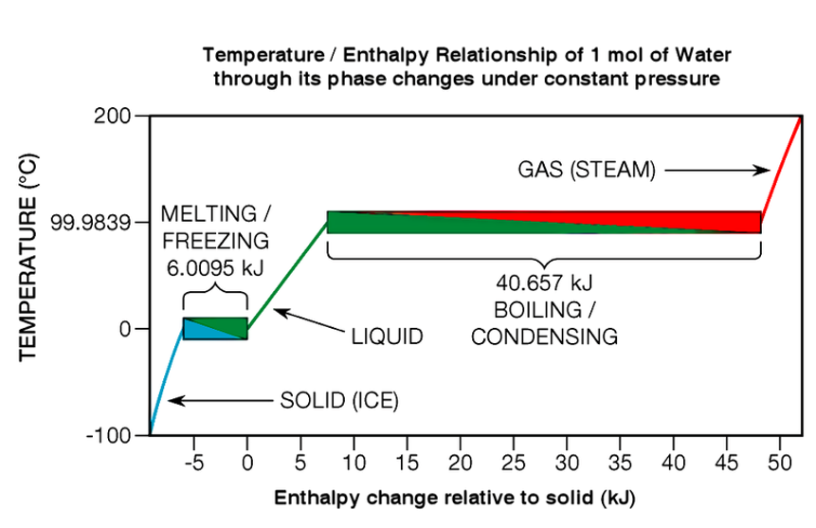
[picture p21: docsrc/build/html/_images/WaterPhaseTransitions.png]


We can see that at the melting and boiling point transitions, there are large changes in the temperature-enthalpy curve -
shown by the horizontal sections - due to the *latent heat*, which must be overcome before the temperature begins to rise 
again. This can be seen on a DTA curve as a temporary peak (or trough) in the temperature difference between the sample 
and reference.

When plotted as a function of the sample's temperature, one can evaluate both the temperature at which a phase transition occurs,
as well as the enthalpy of the transition, by accounting for the heat capacities of the sample and
reference.

.. _start_intro_instrument:

DTA Instrument
--------------

The typical construction of a DTA instrument is shown in the figure below.

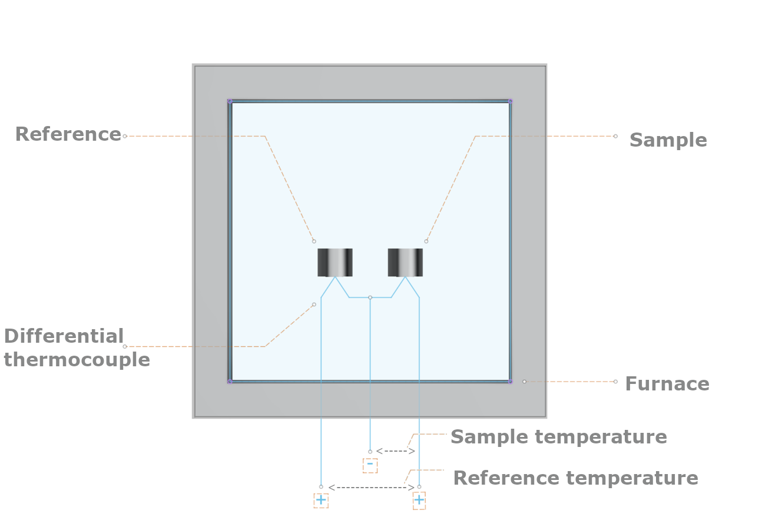
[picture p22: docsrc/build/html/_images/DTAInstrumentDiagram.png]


   **Basic features of a DTA instrument**

The sample and reference are placed in heating pans and heated by a furnace, following a programmed temperature profile.
A differential thermocouple measures the temperature difference between the sample and reference, with an additional
thermocouple measuring the temperature of the reference, resulting in a temperature profile typical of that shown below:

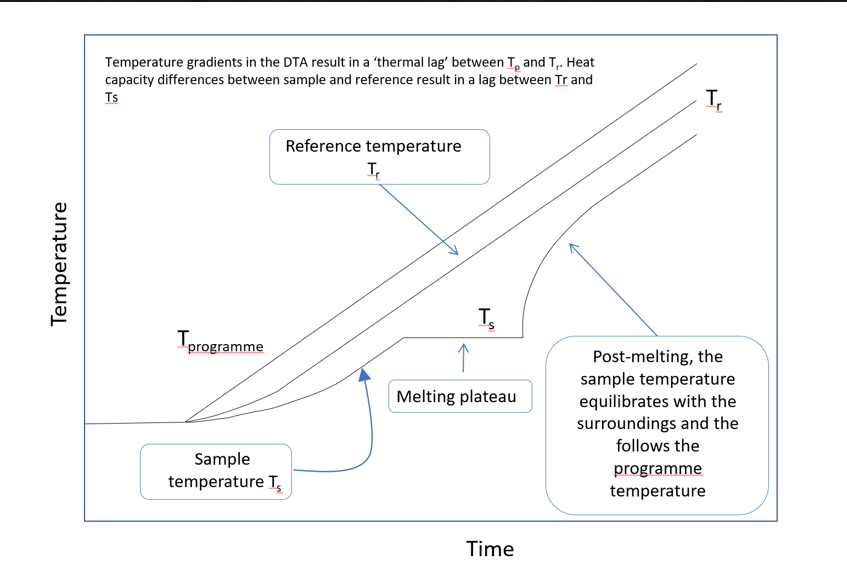
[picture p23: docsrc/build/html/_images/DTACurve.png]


   **Temperature profile of sample and reference, during heating run**

.. rubric:: References

.. [1] https://commons.wikimedia.org/wiki/File:Energy_through_phase_changes.png

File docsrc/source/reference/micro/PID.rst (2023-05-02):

.. _ref_micro_pid:

PID
---

.. py:module:: pid
    :synopsis: This module defines the :class:`PIDState` class, which is 
        responsible for controlling the heat output of the Peltier module
        based on a target temperature or heating rate, using a PID control
        loop.

    Defines the :class:`PIDState` class, which is responsible for controlling
    and regulating the PWM output to the H-bridge, based on the system mode, target
    temperature and heat rate.

    .. py:class:: PIDState(sensor, kp, ki, kd, Ts)

       :param sensor: The temperature sensor used for the PID control loop
       :type sensor: :class:`sensor.TempSensor`
       :param kp: The proportional gain of the PID control loop
       :type kp: float
       :param ki: The integral gain of the PID control loop
       :type ki: float
       :param kd: The derivative gain of the PID control loop
       :type kd: float
       :param Ts: The sampling period of the PID control loop
       :type Ts: float

       :ivar config: Provides a dictionary-like interface for
            configuring the :class:`PIDState` object, such as
            specifying output enable, ramp/hold mode, target
            heat rate / hold temperature and PID parameters.
       :vartype config: :class:`ResponsiveDict`
       :ivar e: The error signal of the PID control loop
       :vartype e: float
       :ivar u: The control signal of the PID control loop
       :vartype u: float

       .. py:method:: temp()
          
          :returns: The current temperature of the sensor used for the PID control loop
          :rtype: float

       .. py:method:: reset()

          Reset PID controller values to defaults

       .. py:method:: update()

          Calculate updated values for PWM output

Code listing
^^^^^^^^^^^^

.. literalinclude:: ./../../../../src/microcontroller/PID.py
   :language: python

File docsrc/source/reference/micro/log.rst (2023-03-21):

.. _ref_micro_log:

log
---

.. py:module:: log
    :synopsis: Defines a :class:`Log` class, used for reading and caching
        data from sensors. 

    Defines the :class:`Log` class, which is responsible for collating 
    simultaneous readings from :class:`sensor.Sensor` objects and
    periodically pushing these to be sent to the computer, via the
    serial connection.

    .. py:class:: Log(interval, sensors=[])
        
       :param interval: Time interval between sensor readings,
           in seconds.
       :type interval: float
       :param sensors: List of :class:`sensor.Sensor` objects to
           read from, defaults to an empty list.
       :type sensors: list

       :ivar sensors: List of :class:`sensor.Sensor` objects to read from
       :type sensors: list
       :ivar config: Provides a dictionary-like interface for
           configuring the :class:`Log` object, such as specifying
           whether sensor readings should be saved.
       :type config: ResponsiveDict
       :ivar readings: Dictionary containing readings from each sensor
           in the :attr:`sensors` list.
       :type readings: dict
       :ivar interval: Time interval between sensor readings,
           in seconds.
       :type interval: float

       **Methods**:

       .. py:method:: add_sensor(new_sensor)

          Add a :class:`sensor.Sensor` object to the :attr:`Log.sensors`
          list.

          :param new_sensor: Sensor to add
          :type sensor: sensor.Sensor

       .. py:method:: update()

          Update the :attr:`Log.readings` dictionary with the latest
          readings from each sensor in the :attr:`Log.sensors` list.

       .. py:method:: read(self num_request)

          Read the latest readings from the :attr:`Log.readings` dictionary.

          :param num_request: Number of readings to return
          :type num_request: int
          :returns: Tuple of the form ``(readings, n)`` where ``readings``
              is a list of the latest ``n`` readings and ``n`` is the
              number of readings returned.
          :rtype: tuple

       .. py:method:: start()

          Start the :class:`Log` object's time sensor 

       .. py:method:: reset()

          Reset all sensors and readings

Code listing
^^^^^^^^^^^^

.. literalinclude:: ./../../../../src/microcontroller/log.py
   :language: python

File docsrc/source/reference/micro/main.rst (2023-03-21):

.. _ref_micro_main:

main
----

.. py:module:: main
    :synopsis: Main programme that is run when the microcontroller powers on.

Code listing
^^^^^^^^^^^^

.. literalinclude:: ./../../../../src/microcontroller/main.py
   :language: python

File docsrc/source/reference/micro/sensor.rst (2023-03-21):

.. _ref_micro_sensor:

sensor
------

.. py:module:: sensor
    :synopsis: Wrapper module

Code listing
^^^^^^^^^^^^

.. literalinclude:: ./../../../../src/microcontroller/sensor.py
   :language: python

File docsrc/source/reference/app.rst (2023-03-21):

.. _ref_app:

app
---

.. automodule:: app

   Widget layout
   ^^^^^^^^^^^^^

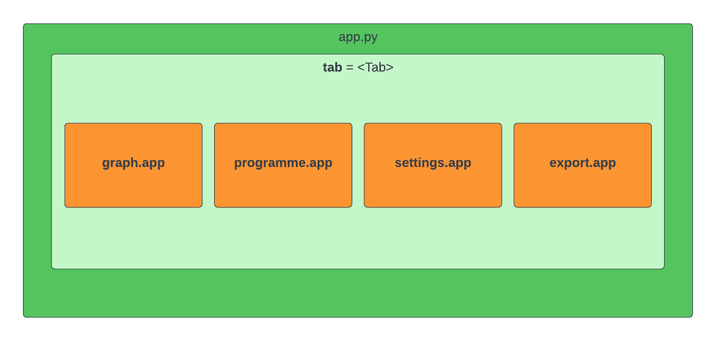
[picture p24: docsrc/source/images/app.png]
Web app UI module structure
   

   |

   Widget objects
   ^^^^^^^^^^^^^^

   |

   .. autodata:: tab
      :annotation: <ipywidgets.widgets.Tab>

   .. jupyter-execute::
        :hide-code:

        import os
        import sys
   
        ROOT_DIR = os.path.abspath('../')
        WEBAPP_PATH = ROOT_DIR + '/src/dashboard/'
        sys.path.insert(0, WEBAPP_PATH)
   
        from app import *

   |

   Helper functions
   ^^^^^^^^^^^^^^^^

   .. autofunction:: work

   .. autofunction:: main

|

Code listing
^^^^^^^^^^^^

.. literalinclude:: ../../../src/dashboard/app.py
    :language: python

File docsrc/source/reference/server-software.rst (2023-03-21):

Interface reference
===================

.. _ref_interface_overview:

Overview
--------

The previous sections covered the implementation of the system-level features
in the web app program [:doc:``_ref_ui_overview``], in addition to the
electronics integration and control handled by the microcontroller program
[:doc:``_ref_micro_overview``].

In order for these two programs to communicate with each other, an additional
python program

Whilst the previous sections covered the implementation of the high-level,
user-facing control of the system [:doc:``_ref_ui_overview``], as well as
the lower-level electronic control routines handled by the
[:doc:``_ref_micro_overview``], the means by which both programs communicate
with each other was not discussed in a lot of detail.

As previously mentioned in the the :doc:`basic` section, the dashboard-style 
user interface for the system is built using a `widget 
<https://ipywidgets.readthedocs.io/en/stable/>`_ based approach, that relies 
on the `Jupyter <https://jupyter.org/>`_ interactive computing platform.

This approach was chosen for the following reasons:

* As a Python-based project, the Jupyter platform is a natural fit, providing a
  popular, well-documented Python environment that is capable of producing rich
  interactive, web-based visualisations, using python libraries and code which 
  should be familiar to undergraduates who have a grounding in Python
  programming.
* Modern web browsers provide an ideal deployment platform for graphical
  applications, offering compatibility across a wide range of devices,
  operating systems and user interfaces (mouse, or touchscreen).

.. _ref_server_description:

app
---

.. automodule:: app

   Widget layout
   ^^^^^^^^^^^^^

   Web app UI module structure

   |

   Widget objects
   ^^^^^^^^^^^^^^

   |

   .. autodata:: tab
      :annotation: <ipywidgets.widgets.Tab>

   .. jupyter-execute::
        :hide-code:

        import os
        import sys
   
        ROOT_DIR = os.path.abspath('../')
        WEBAPP_PATH = ROOT_DIR + '/src/dashboard/'
        sys.path.insert(0, WEBAPP_PATH)
   
        from app import *

   |

   Helper functions
   ^^^^^^^^^^^^^^^^

   .. autofunction:: work

   .. autofunction:: main

|

Code listing
^^^^^^^^^^^^

.. literalinclude:: ../../../src/receive.py
    :language: python

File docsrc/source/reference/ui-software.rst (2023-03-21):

Dashboard (UI) software reference
=================================

.. _ref_ui_overview:

Overview
--------

As previously mentioned in the the :doc:`/usage/basic` section, the dashboard-style 
user interface for the system is built using a `widget 
<https://ipywidgets.readthedocs.io/en/stable/>`_ based approach, that relies 
on the `Jupyter <https://jupyter.org/>`_ interactive computing platform.

This approach was chosen for the following reasons:

* As a Python-based project, the Jupyter platform is a natural fit, providing a
  popular, well-documented Python environment that is capable of producing rich
  interactive, web-based visualisations, using python libraries and code which 
  should be familiar to undergraduates who have a grounding in Python
  programming.
* Modern web browsers provide an ideal deployment platform for graphical
  applications, offering compatibility across a wide range of devices,
  operating systems and user interfaces (mouse, or touchscreen).

.. _ref_ui_structure:

Structure
---------

The underlying Python code for the dashboard application is composed of two main types of files:

* **Widget definition files**, largely composed of ipywidget object declarations, which define the *appearance* of 
  the user interface, in addition to some *local behaviour*, specific to the user elements defined within a given
  file.
* **Utility function files**, containing regular python code that defines useful functions/classes that are then 
  imported in widget definition files and used by the widget objects in them, to effect *global behaviour* of the
  user interface, such as handling of shared data and progression of the application state.

A 'top-level' widget definition file, :file:`app.py`, is then used to bring together the various UI elements defined in the
other files, in a nesting/container-like manner, producing the final dashboard interface.

Web app UI module structure

This approach introduces a great deal of flexibility, when it comes to implementing additional UI elements and
behaviours, as it is only necessary to create a new widget definition file and then import that into the 
top-level script.

The present structure of the UI code includes the following files:

Widget definition files
^^^^^^^^^^^^^^^^^^^^^^^^

.. toctree::
   :maxdepth: 2

   app
   webapp/graph
   webapp/programme
   webapp/settings
   webapp/export

Utility function files
^^^^^^^^^^^^^^^^^^^^^^

.. toctree::
   :maxdepth: 2

   webapp/shared
   webapp/utils

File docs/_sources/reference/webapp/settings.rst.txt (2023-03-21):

.. _ref_webapp_settings:

webapp.settings
---------------

.. automodule:: webapp.settings

    Widget layout
    ^^^^^^^^^^^^^

    .. figure:: ../../images/settings.png
       :align: center
       :scale: 50%
       :alt: Web app UI module structure

    |

    Widget objects
    ^^^^^^^^^^^^^^

    |

    .. autodata:: app
        :annotation: = ConfigTab(config=appState.config)

    .. jupyter-execute::
        :hide-code:
    
        import os
        import sys
    
        ROOT_DIR = os.path.abspath('../')
        WEBAPP_PATH = ROOT_DIR + '/src/dashboard/'
        sys.path.insert(0, WEBAPP_PATH)
    
        from webapp.settings import *
        display(app)

    |

    Helper classes
    ^^^^^^^^^^^^^^

    .. autoclass:: ConfigTab

    |

    .. autoclass:: ControlSlider

    |

    .. jupyter-execute::
        :hide-code:

        import os
        import sys

        ROOT_DIR = os.path.abspath('../')
        WEBAPP_PATH = ROOT_DIR + '/src/dashboard/'
        sys.path.insert(0, WEBAPP_PATH)

        from webapp.settings import ControlSlider
        from webapp.shared import appState

        app = ControlSlider(appState.config, 'KP')
        display(app)

|

Code listing
^^^^^^^^^^^^

.. literalinclude:: ../../../../src/dashboard/webapp/settings.py
    :language: python

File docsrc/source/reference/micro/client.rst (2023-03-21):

.. _ref_micro_client:

client
------

.. py:module:: client
   :synopsis: Defines the :class:`SerialClient` class, responsible for 
       handling communication between microcontroller and computer

   This module defines the :class:`SerialClient` class, which is responsible
   for handling serial communication between the microcontroller and the
   python code running on the connected small board computer.

   .. py:class:: SerialClient(serial=usb_cdc.data, buf_out_size=1024,
      read_timeout=0.01, write_timeout=0.015)

      :param serial: The serial device instance to use, defaults to
          :data:`usb_cdc.data`
      :type serial: :class:`serial.Serial`
      :param buf_out_size: Size of output buffer in bytes, defaults to 1024
      :type buf_out_size: int
      :param read_timeout: Read timeout period, specifying how long to read
          the serial line, before yielding to a write operation, defaults to
          0.01s
      :type read_timeout: float
      :param write_timeout: Write timeout period, specifying how long to spend
          writing to the serial line, before yielding to a read operation,
          defaults to 0.015s
      :ivar serial: The serial device the object is using
      :type serial: :class:`serial.Serial`
      :ivar buf_out_bytes_free: Number of free bytes available to write to in
          :attr:`buf_out`
      :type buf_out_bytes_free: int
      :ivar buf_in: Input buffer for storing messages received over serial line
      :type buf_in: :class:`bytearray`
      :ivar buf_out: Output buffer for storing messages to be sent over serial
          line
      :type buf_out: :class:`bytearray`

      **Methods**:

      .. py:method:: SerialClient.write(data)

         Perform an immediate write of ``data`` to the serial line,
         bypassing data in :attr:`SerialClient.buf_out`

         :param data: Byte-encoded message to be written to the serial line
         :type data: bytes
         :return: Status code indicating the number of bytes written
         :rtype: int

      .. py:method:: SerialClient.update()

         Perform a read/write operation on the serial line, reading any
         data sent from the computer into :attr:`SerialClient.buf_in` and
         writing data in :attr:`SerialClient.buf_out` out to the computer.

Code listing
^^^^^^^^^^^^

.. literalinclude:: ./../../../../src/microcontroller/client.py
   :language: python

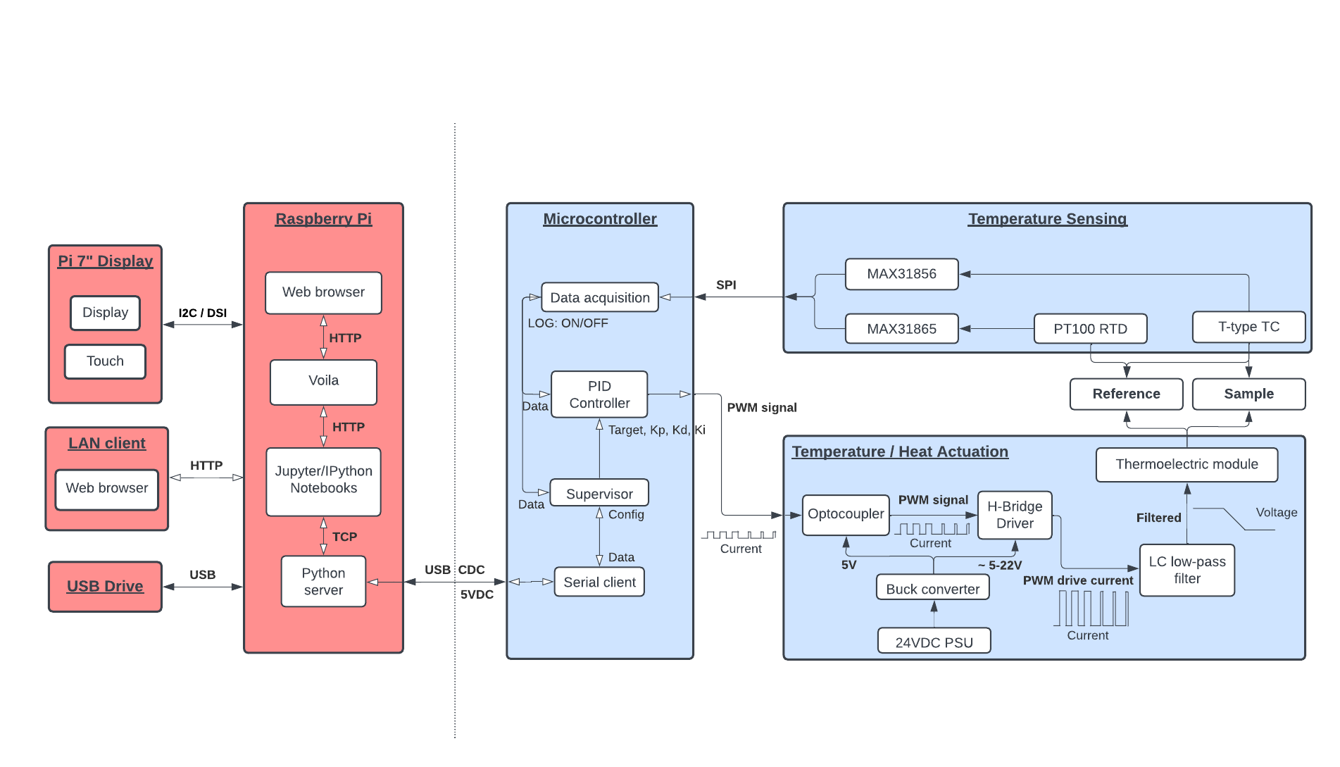
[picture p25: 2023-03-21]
docsrc/source/images/HardwareDetailView.png

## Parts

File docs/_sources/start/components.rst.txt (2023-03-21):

Components
==========

.. _start_components_shelf:

Off-the-Shelf Parts
-------------------

The system utilises the following components:

* Raspberry Pi Model B (3+/4), running Raspbian Buster, or newer - `Raspberry Pi 4 Model B <https://www.raspberrypi.com/products/raspberry-pi-4-model-b/>`_.
* Official Raspberry Pi 7" Touchscreen Display - `7" Touchscreen Display <https://www.raspberrypi.org/products/raspberry-pi-touch-display/>`_.
* Raspberry Pi Pico microcontroller - `Raspberry Pi Pico <https://www.raspberrypi.org/products/raspberry-pi-pico/>`_.
* Micro USB cable
* Breakout boards from Adafruit, including:

    * 2x Adafruit MAX31865 RTD Temperature Sensor boards - `MAX31865 RTD Sensor <https://www.adafruit.com/product/3328>`_
    * 2x Adafruit MAX31856 Thermocouple Amplifier boards - `MAX31856 Thermocouple Amplifier <https://www.adafruit.com/product/3263>`_

* Temperature sensors:

    * 2x 4-wire PT100 RTD sensors - `PT100 RTD Sensor <https://uk.rs-online.com/web/p/rtd-sensors/8919141>`_
    * 2x Type T thermocouples - `Type T Thermocouple <https://uk.rs-online.com/web/p/thermocouples/0158907>`_
    * 1x Type (K/T) thermocouple - `Type (K/T) Thermocouple <https://uk.rs-online.com/web/p/thermocouples/0158907>`_

* Motor Controller board by Cytron Technologies: HAT-MDD10 - `HAT-MDD10 <https://www.cytron.io/p-hat-mdd10>`_

    .. image:: /images/HAT-MDD10A.jpg
        :width: 400px
        :align: center
        :alt: HAT-MDD10 Motor Controller board

* 2x 12V DC motors - `12V DC Motor <https://uk.rs-online.com/web/p/dc-motors/0908152>`_
* An adjustable DC Power Supply, capable of providing up to 20V at 5A or greater
* A capable thermoelectric module (TEC) device, able to pump >10W of heat

.. _start_components_custom:

Interface boards
----------------

A set of PCB interface boards are used to connect the microcontroller, breakout boards and other components, the
files of which are available in the `Github repository. <https://github.com/TomFahey/DTA-MSc-Project/tree/master/pcb>`_

These consist of the following:

.. _start_components_custom_microcontroller_board:

* Microcontroller and temperature sensor interface board

    .. image:: /images/MicrocontrollerTemperatureSensorBoard.png
        :width: 400px
        :align: center
        :alt: Microcontroller and temperature sensor interface board

    Interfaces with the Raspberry Pi Pico microcontroller and the temperature sensor
    breakout boards.

.. _start_components_custom_motor_board:

* Motor controller interface board

    .. image:: /images/MotorControllerBoard.png
        :width: 400px
        :align: center
        :alt: Motor controller interface board

    Interfaces with the HAT-MDD10 motor controller board, via the 40-pin GPIO header, as
    well as the DC power supply.

.. _start_components_custom_tem_board:

* Thermoelectric module interface board

    .. image:: /images/ThermoelectricModuleBoard.png
        :width: 400px
        :align: center
        :alt: Thermoelectric module interface board

    Interfaces with the thermoelectric module(s)

The boards connected to each other via Molex 6-pin Micro-Fit cables, available `here. <https://uk.rs-online.com/web/p/wire-to-board-cables/2134263>`_

..
    Creating recipes
    ----------------

    To retrieve a list of random ingredients,
    you can use the ``lumache.get_random_ingredients()`` function:

    .. autofunction:: lumache.get_random_ingredients

    The ``kind`` parameter should be either ``"meat"``, ``"fish"``,
    or ``"veggies"``. Otherwise, :autofunction`lumache.get_random_ingredients`
    will raise an exception.

    .. autoexception:: lumache.InvalidKindError

    >>> import lumache
    >>> lumache.get_random_ingredients()
    ['shells', 'gorgonzola', 'parsley']

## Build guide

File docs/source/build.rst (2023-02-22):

Build/Installation
=====

.. _build:

Build
-----

The DTA utilises the following off-the-shelf parts:

* Raspberry Pi Model B (3+/4), running Raspbian Buster, or newer - `Raspberry Pi OS <https://www.raspberrypi.org/software/>`_.
* Official Raspberry Pi 7" Touchscreen Display - `7" Touchscreen Display <https://www.raspberrypi.org/products/raspberry-pi-touch-display/>`_.
* Raspberry Pi Pico microcontroller - `Raspberry Pi Pico <https://www.raspberrypi.org/products/raspberry-pi-pico/>`_.
* Breakout boards from Adafruit, including:

    * 2x Adafruit MAX31865 RTD Temperature Sensor boards - `MAX31865 RTD Sensor <https://www.adafruit.com/product/3328>`_
    * 2x Adafruit MAX31856 Thermocouple Amplifier boards - `MAX31856 Thermocouple Amplifier <https://www.adafruit.com/product/3263>`_

* Temperature sensors:

    * 2x 4-wire PT100 RTD sensors - `PT100 RTD Sensor <https://www.adafruit.com/product/3328>`_
    * 2x Type T thermocouples - `Type T Thermocouple <https://www.adafruit.com/product/269>`_
    * 1x Type (K/T) thermocouple - `Type (K/T) Thermocouple <https://www.adafruit.com/product/3263>`_

* Motor Controller board by Cytron Technologies: HAT-MDD10 - `HAT-MDD10 <https://www.cytron.io/p-hat-mdd10>`_
* An adjustable DC Power Supply, capable of providing up to 20V at 5A or greater

As well as a number of custom PCBs, the files for which can be found on the project Github page.

.. _installation:

Installation
------------

To install the user interface software on the Raspberry Pi, you can use the following commands:

.. code-block:: console

   $ git clone https://github.com/TomFahey/DTA-MSC-Project.git
   $ cd DTA-MSC-Project
   $ sudo python setup.py install

This will install the project, and all of its dependencies, after which the user interface service will start automatically.

..
    Creating recipes
    ----------------

    To retrieve a list of random ingredients,
    you can use the ``lumache.get_random_ingredients()`` function:

    .. autofunction:: lumache.get_random_ingredients

    The ``kind`` parameter should be either ``"meat"``, ``"fish"``,
    or ``"veggies"``. Otherwise, :autofunction`lumache.get_random_ingredients`
    will raise an exception.

    .. autoexception:: lumache.InvalidKindError

    >>> import lumache
    >>> lumache.get_random_ingredients()
    ['shells', 'gorgonzola', 'parsley']

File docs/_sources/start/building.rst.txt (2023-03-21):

Building
========

Assuming that you have all of the required components listed in the 
:doc:`components` sections, building the system is relatively
straightforward.

.. _start_build_solder_jumpers:

Setting the solder jumpers
--------------------------

Before using the interface boards for the first time, you will need to set the 
four solder jumpers on the 
:ref:`microcontroller interface board <_start_components_custom_microcontroller_board>`,
according to the temperature sensing breakout boards you intend to use. 

Each solder jumper has three pads, which collectively form a switch. To use the
Adafruit MAX31865 (RTD sensors) at Header 1, for example, you should solder the
middle pad to the 'RTD' pad on the right. Likewise, for the MAX31856 
(Thermocouple sensors), solder the middle pad to the 'TC' pad on the left. All
four solder jumpers can be continuously reconfigured, as required.

.. figure:: /images/SolderJumperCloseup.png
    :width: 800px
    :align: center
    :alt: Solder jumpers on the interface board, with SJ2 configured for RTD 
        sensors.

    **Solder jumpers on the interface board, with example of SJ2 configured for 
        RTD sensors.**

.. _start_build_connecting:

Connecting up the boards
------------------------

Inter-board connections
^^^^^^^^^^^^^^^^^^^^^^^

The figure below shows the connections for the interface boards:

.. figure:: /images/BoardConnectionDiagram.png
    :width: 800px
    :align: center
    :alt: Connections for the interface boards

For the wires connecting the DC Power Supply, make sure to use an appropriate 
gauge, keeping in mind the current draw the thermoelectric module is likely to
have (5A is a safe, if slightly overly overcautious, assumption).

Motor controller interface board
^^^^^^^^^^^^^^^^^^^^^^^^^^^^^^^^

After connecting the HAT-MDD10A to the 
:ref:`motor controller interface board <_start_components_custom_motor_board>`, 
via the the 40-pin header, the vertically stacked terminal blocks should be
connected together like so (once again taking into consideration the current 
draw):

.. figure:: /images/MotorHatWiring.png
    :width: 800px
    :align: center
    :alt: Stacked terminal blocks

It's a good idea to use slightly longer wires for the connections between the 
terminals, so that the motor controller can be lifted off the interface board,
without having to continuously disconnect and reconnect the wires.

Temperature breakout boards
^^^^^^^^^^^^^^^^^^^^^^^^^^^

The temperature breakout boards connect to the microcontroller interface board
via the female 8-pin headers. In the case of the MAX31856, which has a 9-pin
male header, the 9th pin (DRDY) is not used, so can be left unconnected.

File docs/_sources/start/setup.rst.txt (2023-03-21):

Setup
=====

.. _start_setup_installation:

Installation
------------

To install the user interface software on the Raspberry Pi, you can use the 
following commands:

.. code-block:: console

   $ git clone https://github.com/TomFahey/DTA-MSC-Project.git
   $ cd DTA-MSC-Project
   $ pip install -r requirements.txt
   $ sudo mkdir -p /usr/local/bin/DTA/dashboard
   $ sudo cp -r src/dashboard /usr/local/bin/DTA/
   $ sudo cp src/receive.py /usr/local/bin/DTA/
   $ sudo cp etc/systemd/* /etc/systemd/system/
   $ sudo systemctl daemon-reload
   $ sudo systemctl enable DTA-jupyter.service DTA-chrome.service DTA-interface.service
   $ sudo systemctl start DTA-jupyter.service DTA-chrome.service DTA-interface.service

This will install the project, and all of its dependencies, after which the 
user interface service will start automatically.

To disable the user interface service, you can use the following command:

.. code-block:: console

   $ sudo systemctl disable DTA-jupyter.service DTA-chrome.service DTA-interface.service
   $ sudo systemctl stop DTA-jupyter.service DTA-chrome.service DTA-interface.service

Before installing the microcontroller code to the Raspberry Pi Pico, you will need to
install the CircuitPython UF2 bootloader. To do this, you can follow the instructions
provided on the `Adafruit <https://learn.adafruit.com/getting-started-with-raspberry-pi-pico-circuitpython/circuitpython>`_
website.

Once CircuitPython is installed, to install the microcontroller code, simply mount the Pico's filesystem
and copy the contents of the ``src/microcontroller/`` directory to the root of the filesystem.

.. code-block:: console

   $ sudo cp -r src/microcontroller/* <PICO_MOUNTPOINT>

The microcontroller code will then be automatically compiled and flashed to the Pico. Once the
command completes, the Pico will automatically reboot.

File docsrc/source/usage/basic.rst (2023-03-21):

Basic Usage
===========

.. _usage_basic_background:

Background
------------

The user interface for the system is built using the `Jupyter Widgets <https://ipywidgets.readthedocs.io/en/stable/>`_ 
interactive browser controls for `Jupyter notebooks <https://jupyter.org/>`_, using `voila <https://voila.readthedocs.io/en/stable/index.html>`_
to render the notebook as a web application. More details on this can be found in the :doc:`reference/software` section.

This automatically launches within the web browser, presenting the user interface on the touchscreen display.

.. _usage_basic_ui:

User Interface
--------------

.. jupyter-execute::
    :hide-code:

    import os
    import sys

    ROOT_DIR = os.path.abspath('../')
    WEBAPP_PATH = ROOT_DIR + '/src/dashboard/'
    sys.path.insert(0, WEBAPP_PATH)

    from app import *

The user interface is presented as a series of navigable tabs, which
are accessed by the tab bar at the top.

Web app interface

Each tab provides a different set of widgets for either controlling or
configuring the system.

.. _usage_basic_ui_main:

Main tab
^^^^^^^^

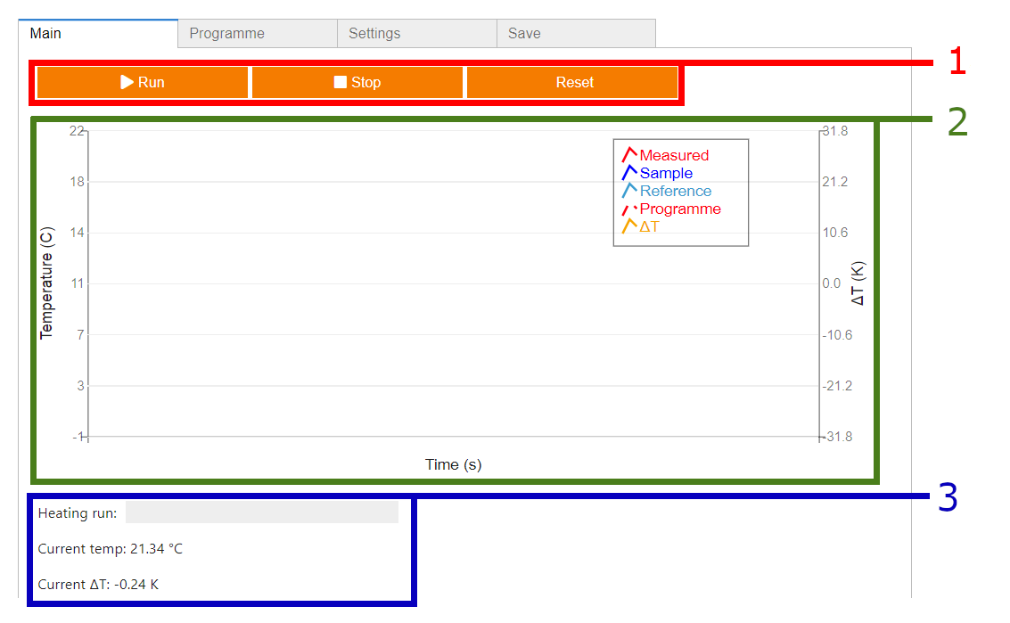
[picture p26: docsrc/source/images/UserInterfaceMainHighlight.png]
Web app interface


The main tab features the following user interface elements:

1. The control bar, which is used for initiating
   and (manually) stopping heating runs, as well as clearing any currently saved data
   and the current heating programme.
2. The graph figure, which is used to display a preview of the entered
   heating programme, as well as the temperature profile of the temperature sensors when
   a heating run is in progress.
3. The status bar, which features a real-time readout of the
   system temperature, as well as the progress of an active heating run.

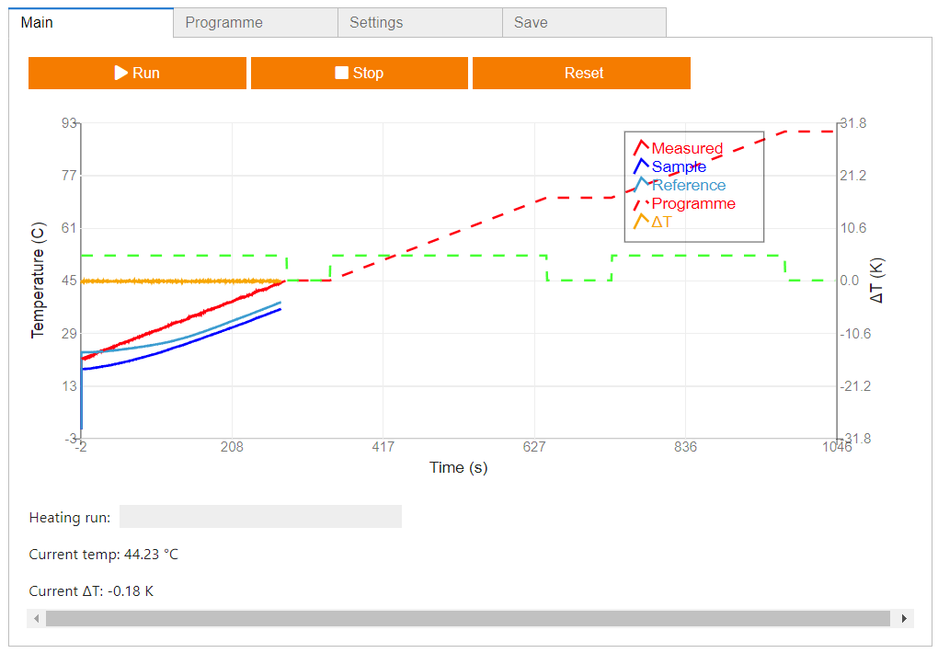
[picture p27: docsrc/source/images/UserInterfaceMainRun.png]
Web app interface


.. _usage_basic_ui_programme:

Programme tab
^^^^^^^^^^^^^

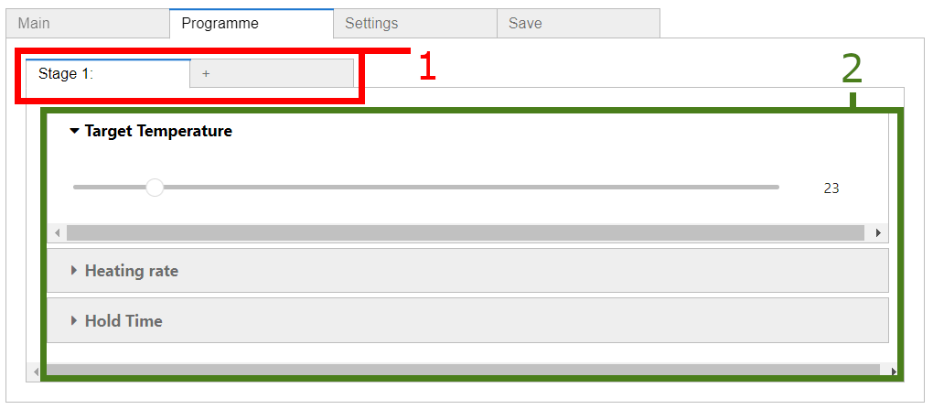
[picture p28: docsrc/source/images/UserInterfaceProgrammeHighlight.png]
Web app interface


The programme tab features the following user interface elements:

1. List of programme **stages**. Additional **stages** can be added by clicking 
   the '+' button.
   
2. Adjustable sliders for the selected stage's parameters

A given heating run **programme** consists of a number of heating **stages**,
each of which are defined by a *target temperature*, *heating rate* and
*hold time*. Each **stage** consists of:

1. A heating ramp, starting from the previous stage's target temperature,
   till the current stage's *target temperature* is reached. This proceeds
   at the specified *heating rate*.
2. A hold period, where the temperature is maintained at the *target temperature*
   for the *hold time*.

After setting up a heating programme, a preview of the programme is
displayed in the graph figure of the main tab.

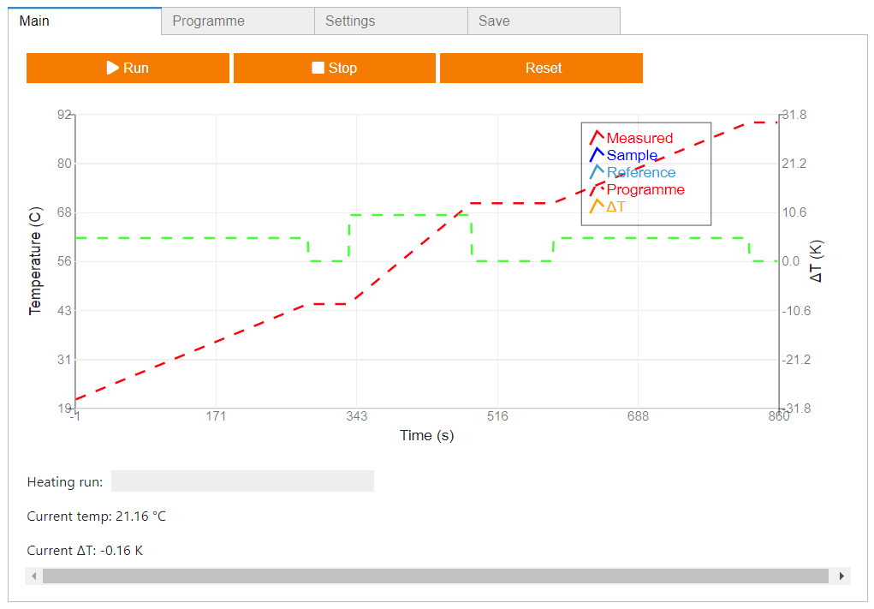
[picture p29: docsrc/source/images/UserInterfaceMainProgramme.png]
Web app interface


.. _usage_basic_ui_settings:

Settings tab
^^^^^^^^^^^^

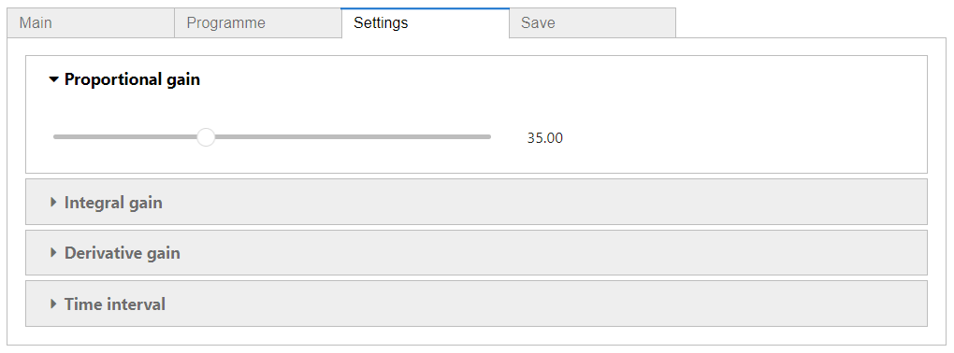
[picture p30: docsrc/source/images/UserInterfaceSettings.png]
Web app interface


The settings tab features a number of drop-down sliders, for setting The
following system parameters:

* PID tuning parameters for the temperature control loop. The temperature
  control loop is implemented using a PID controller, the parameters of
  which can be tuned here, to achieve the desired temperature response.
  The ideal values of the parameters will vary, depending on the details of
  the thermal setup of the system, such as the current-voltage response of the 
  thermoelectric module used.
* The microcontroller tick rate. This is the rate at which the temperature sensors
  are sampled, and the PID controller updated. The default value of 0.25s is recommended.

.. _usage_basic_ui_export:

Export tab
^^^^^^^^^^

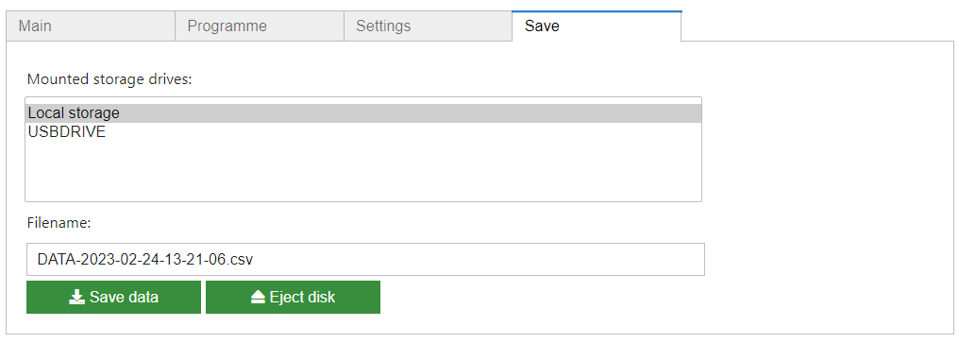
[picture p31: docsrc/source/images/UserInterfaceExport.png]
Web app interface


The export tab is used for saving temperature data after a heating run. 
When a heating run is finished, the recorded data is stored, after which
the system will revert to the idle state. To save the recorded data of a
run, the user should specify a filename and storage location in the export
tab, and click the 'Save data' button

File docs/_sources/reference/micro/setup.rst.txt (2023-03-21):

.. _ref_micro_setup:

setup
-----

.. py:module:: setup
    :synopsis: Setup script for the microcontroller programme.

    This module acts as a setup script for the microcontroller programme,
    providing pin definitions and configuration values for bus devices,
    then initialising them.

Code listing
^^^^^^^^^^^^

.. literalinclude:: ./../../../../src/microcontroller/setup.py
   :language: python

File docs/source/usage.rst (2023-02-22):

Usage
=====

.. _web:

Web Interface
------------

To use Lumache, first install it using pip:

.. code-block:: console

   (.venv) $ pip install lumache

..
   Creating recipes
   ----------------
   
   To retrieve a list of random ingredients,
   you can use the ``lumache.get_random_ingredients()`` function:
   
   .. autofunction:: lumache.get_random_ingredients
   
   The ``kind`` parameter should be either ``"meat"``, ``"fish"``,
   or ``"veggies"``. Otherwise, :autofunction`lumache.get_random_ingredients`
   will raise an exception.
   
   .. autoexception:: lumache.InvalidKindError
   
   >>> import lumache
   >>> lumache.get_random_ingredients()
   ['shells', 'gorgonzola', 'parsley']

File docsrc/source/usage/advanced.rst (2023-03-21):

Advanced Usage
==============

.. _usage_advanced_jupyter:

The Jupyter environment
-----------------------

As mentioned in :ref:`_usage_basic_background`, the python code used for the 
user interface runs inside a Jupyter environment.

This works in the following manner:

* A **Jupyter Server** is started in the ``/src/dashboard/`` folder, under the
  root installation directory for the project. 
* This folder contains the following files:

   *  ``webapp.ipynb`` (a 
      `IPython notebook <https://ipython.org/ipython-doc/3/notebook/notebook.html>`_
      file)
   * ``app.py`` - a regular python file, that acts as the ``__main__.py`` file
     for the dashboard app
   * ``/src/dashboard/webapp`` folder - this contains the python modules defining
     the interactive UI widgets used by the dashboard app, as well as additional
     utility modules.

* The **Jupyter Server** automatically starts up a **Jupyter environment** (see
  picture below), which is accessible as a webpage on the Raspberry Pi's local network.
  This environment allows users to open ``*.ipynb`` files and execute python code
  contained within the notebook's cells, within a python kernel.
* ``webapp.iypnb`` features a single cell, containing the IPython notebook
  magic command ``%run app.py``. This instructs Jupyter to run all the code in
  the file ``app.py`` when the cell is executed.
* The python code in ``app.py`` sets up the dashboard application, which is composed
  of UI widgets such as buttons, graphs, tabs, sliders etc. which is then rendered
  underneath the cell.

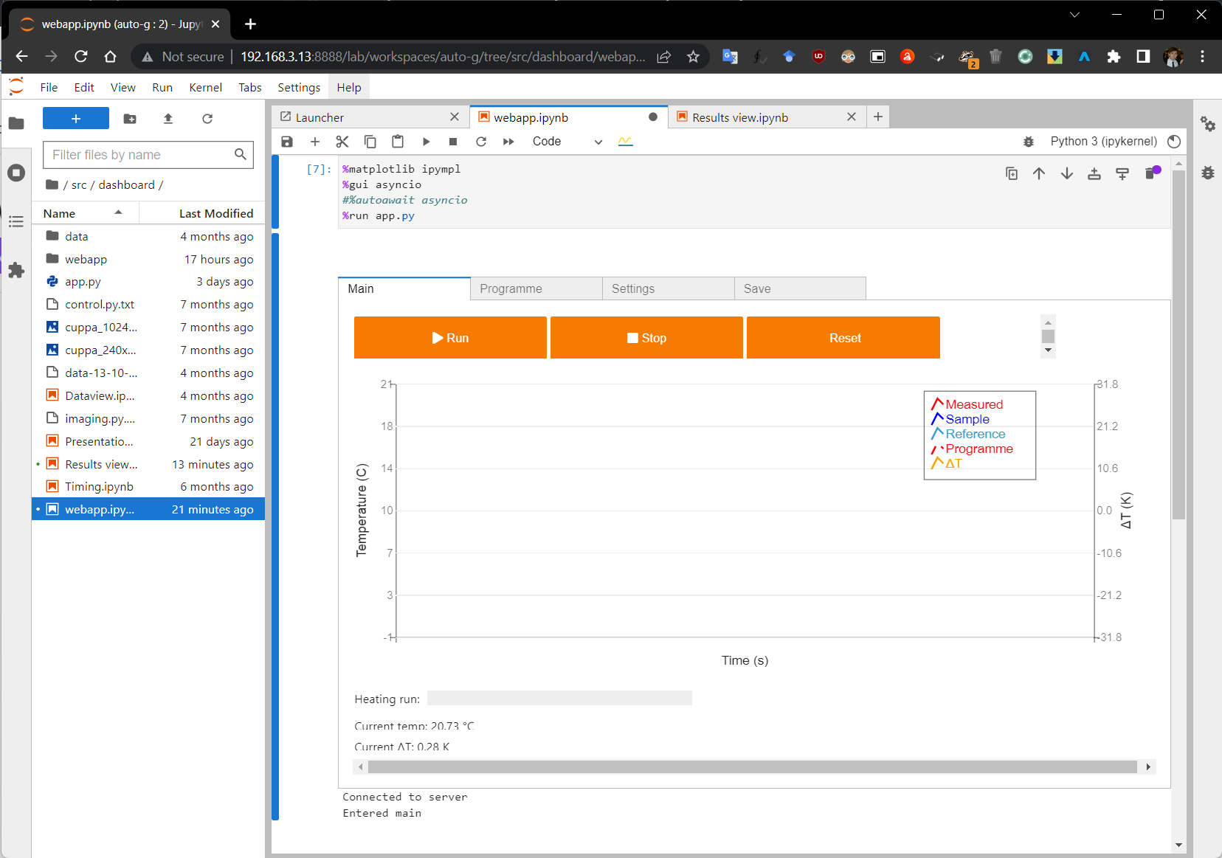
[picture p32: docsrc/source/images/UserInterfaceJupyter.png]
Jupyter notebook environment


Clearly, rendering the dashboard app as a notebook cell's output results in a
sub-optimal user interface, due to the space taken by the **Jupyter
environment** itself.

To get around this, a Jupyter Server extension called 
`voila <https://voila.readthedocs.io/en/stable/index.html>`_
is used to render the app as a standalone web application, resulting in the
final UI shown on the touchscreen.

.. _usage_advanced_using_jupyter:

Using the Jupyter environment
-----------------------------

As mentioned above, the dashboard-style web application is intended to provide 
a streamlined user interface which approximates those found on existing commercial
DTA/DSC instruments, with the idea that it should be similarly easy to use in the lab.

However, for those interested in getting more direct access to data, or system
behaviour, the Jupyter environment provides an excellent means to do so, owing to
the live, interactive nature of Jupyter notebooks.

With direct access to the Python kernel which the application runs in, users can
directly interact with data structures relating to sensor measurements or the
application's state itself. And because this is all within a regular Python kernel,
any external libraries that users wish to make use of can be imported, such as
NumPy/SciPy, Matplotlib, Pandas etc. with the benefit of rich, graphical output,
right within the notebook itself.

This facilitates rapid development of new features, allowing users to type in
python code and see the effect immediately.

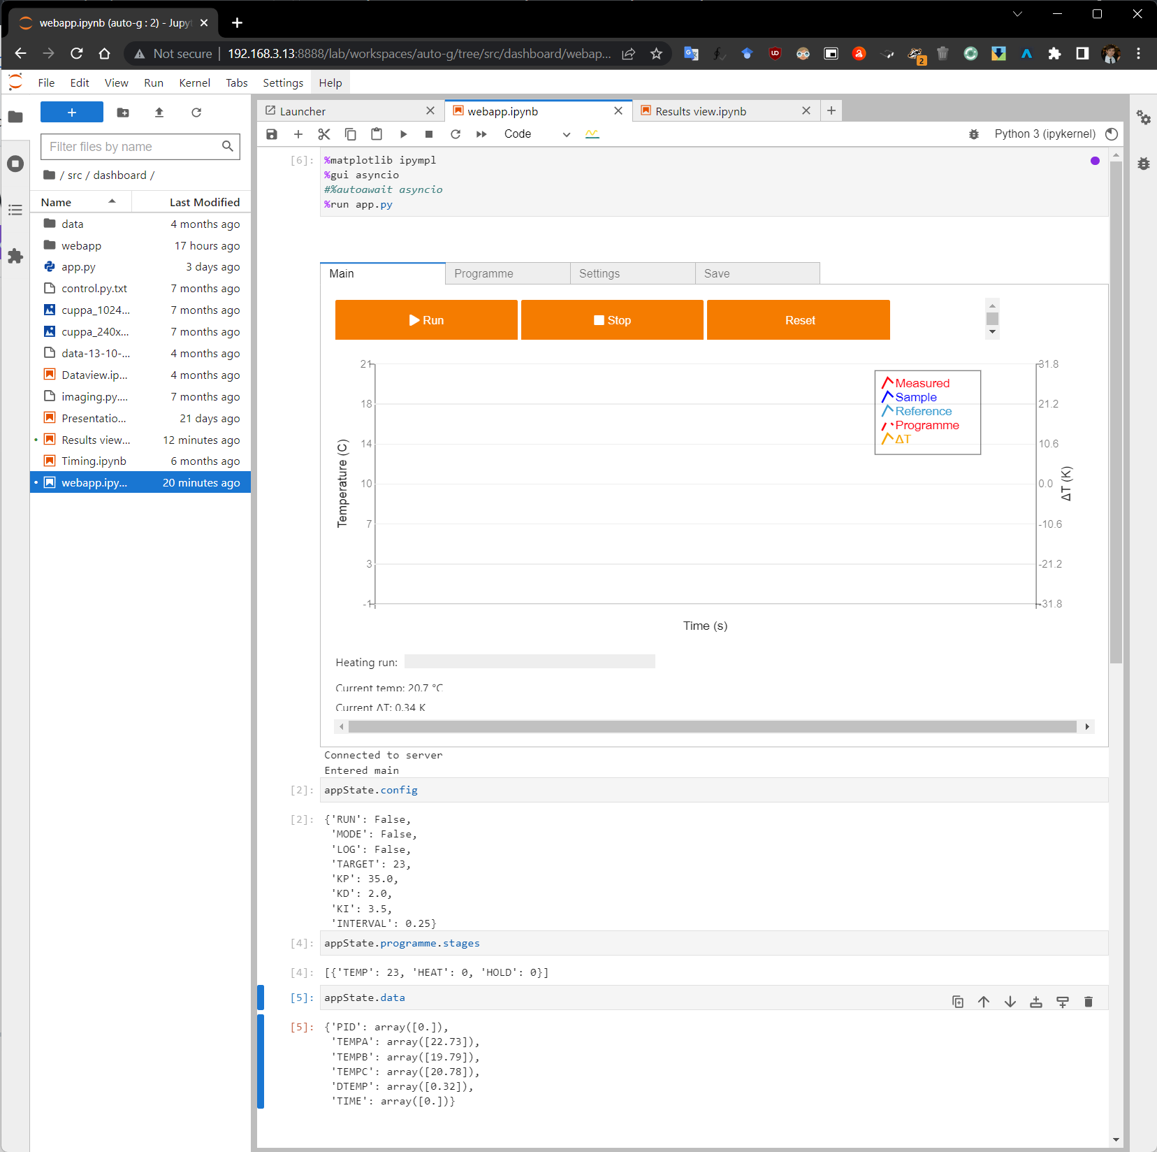
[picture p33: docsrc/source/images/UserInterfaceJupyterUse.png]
Jupyter notebook environment


   Inspecting system state and data with simple Python commands

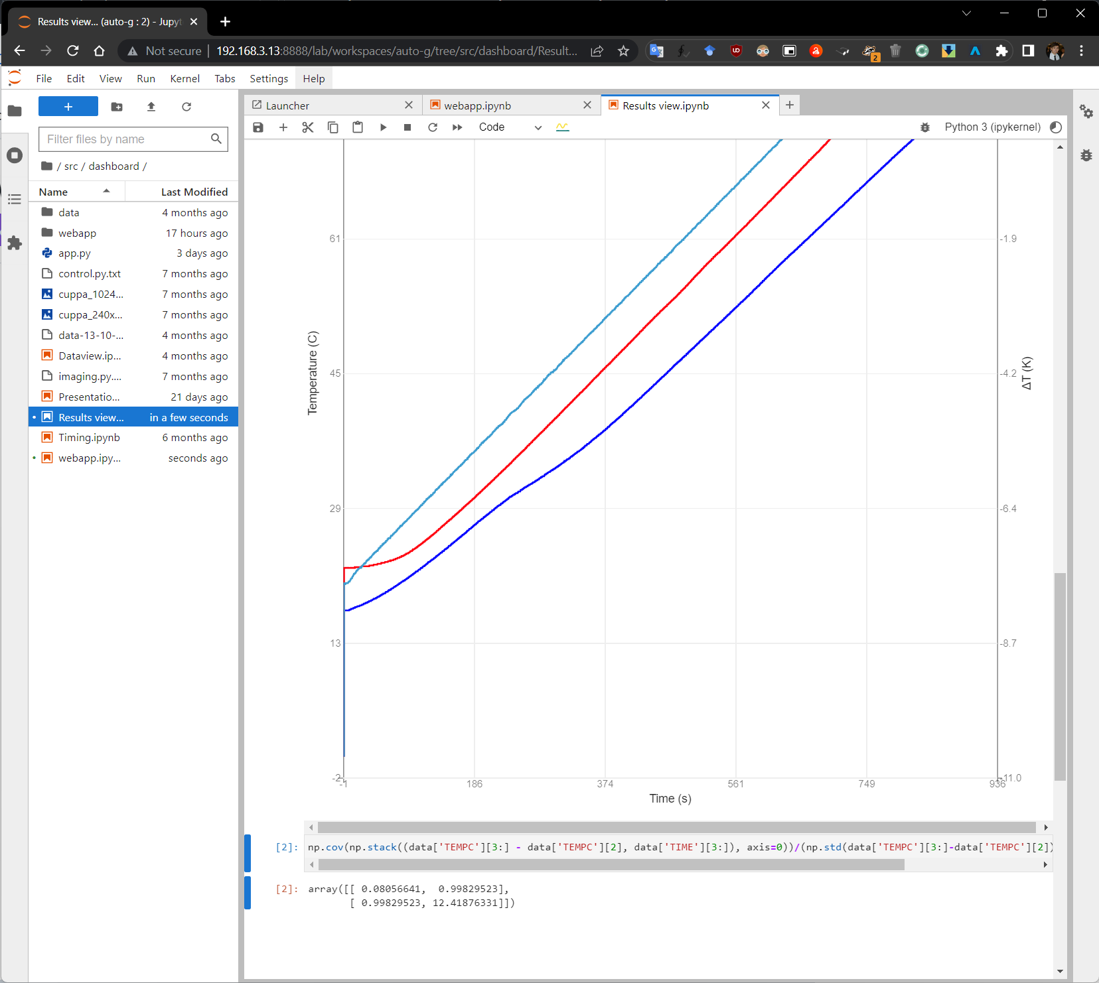
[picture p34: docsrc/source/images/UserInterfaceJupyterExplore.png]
Jupyter notebook environment


   Calculating covariance matrix of temperature against time,
   using the Numpy library.

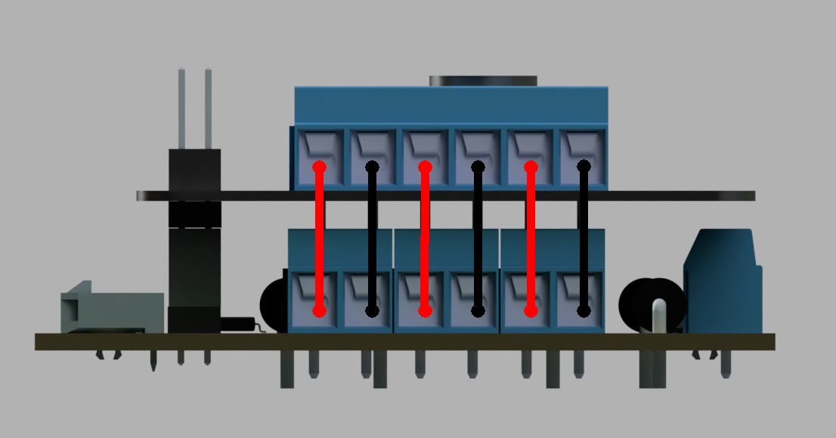
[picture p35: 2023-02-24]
docsrc/source/images/MotorHatWiring.png

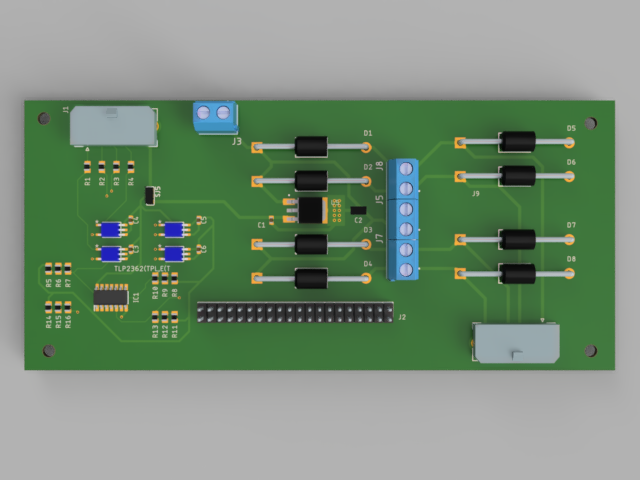
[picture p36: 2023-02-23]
docsrc/build/html/_images/MotorControllerBoard.png

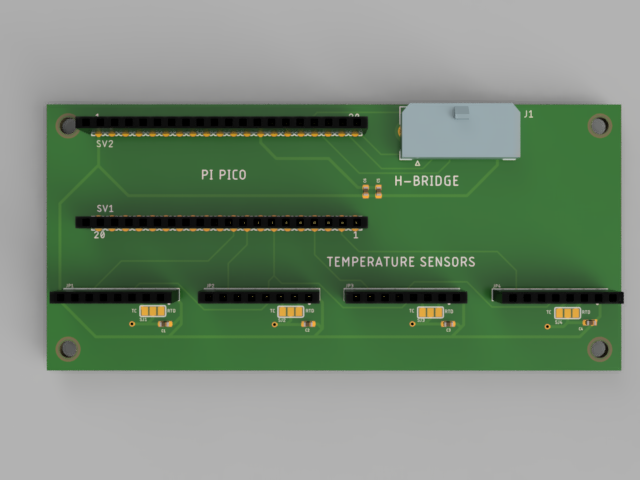
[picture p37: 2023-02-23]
docsrc/build/html/_images/MicrocontrollerTemperatureSensorBoard.png

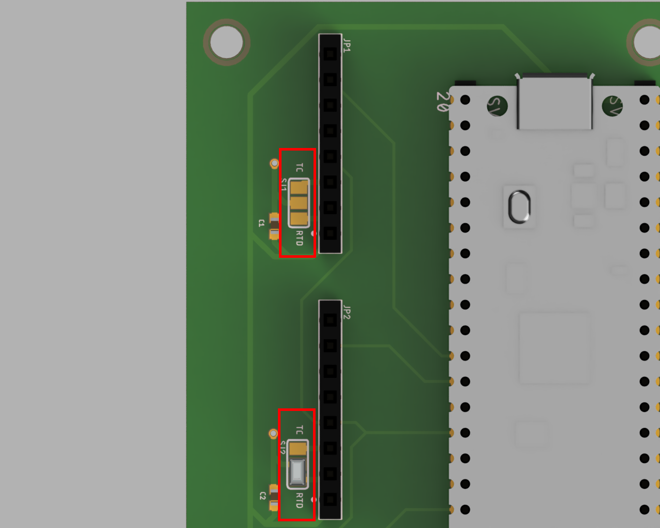
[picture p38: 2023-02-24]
docsrc/source/images/SolderJumperCloseup.png

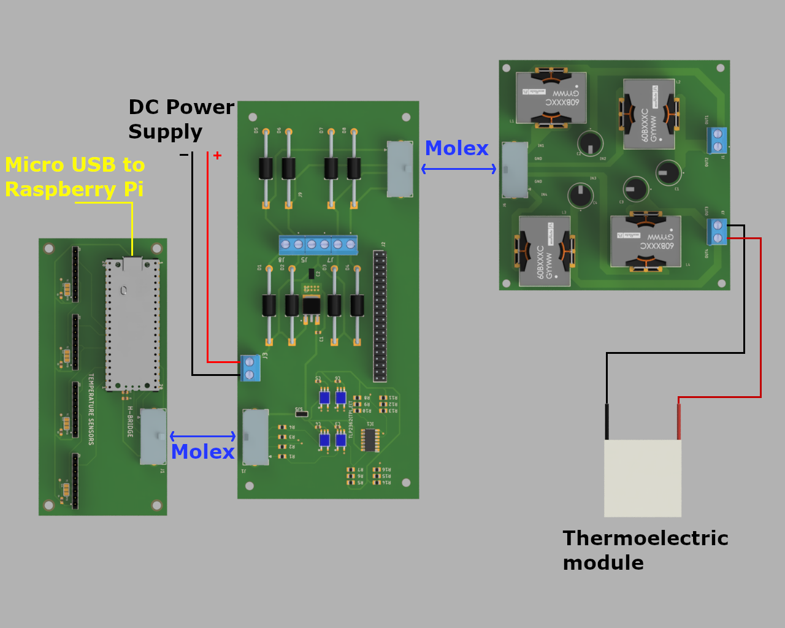
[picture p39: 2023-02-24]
docsrc/build/html/_images/BoardConnectionDiagram.png

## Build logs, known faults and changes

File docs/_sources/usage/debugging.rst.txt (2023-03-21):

Debugging
=========

.. _usage_debugging_systemd:

Checking systemd service units
------------------------------

If you are having problems with loading the user interface, the easiest thing to
check is whether the service units are running. You can check this by running

.. code-block:: bash

   $ sudo systemctl status DTA-jupyter.service
   $ sudo systemctl status DTA-interface.service
   $ sudo systemctl status DTA-chrome.service

These should return messages that look like the following:

.. code-block:: bash

   ● DTA-jupyter.service - Jupyter server instance serving web accessible GUI for connected DTA instrument
      Loaded: loaded (/etc/systemd/system/DTA-jupyter.service; enabled; vendor preset: enabled)
      Active: active (running) since Wed 2023-03-01 10:43:22 GMT; 24h ago
    Main PID: 19453 (jupyter-server)
       Tasks: 1 (limit: 4915)
      CGroup: /system.slice/DTA-jupyter.service
              └─19453 /usr/bin/python3 /home/pi/.local/bin/jupyter-server /home/pi/Pi-Pico-Prototype

   Mar 01 10:43:39 raspberrypi jupyter-server[19453]: [I 2023-03-01 10:43:39.918 ServerApp] notebook_shim | extension was successfully loaded.
   Mar 01 10:43:39 raspberrypi jupyter-server[19453]: [I 2023-03-01 10:43:39.928 LabApp] JupyterLab extension loaded from /home/pi/.local/lib/pytho
   Mar 01 10:43:39 raspberrypi jupyter-server[19453]: [I 2023-03-01 10:43:39.929 LabApp] JupyterLab application directory is /home/pi/.local/share/
   Mar 01 10:43:39 raspberrypi jupyter-server[19453]: [I 2023-03-01 10:43:39.967 ServerApp] jupyterlab | extension was successfully loaded.
   Mar 01 10:43:40 raspberrypi jupyter-server[19453]: [I 2023-03-01 10:43:40.005 ServerApp] voila.server_extension | extension was successfully loa
   Mar 01 10:43:40 raspberrypi jupyter-server[19453]: [I 2023-03-01 10:43:40.009 ServerApp] Serving notebooks from local directory: /home/pi/Pi-Pic
   Mar 01 10:43:40 raspberrypi jupyter-server[19453]: [I 2023-03-01 10:43:40.009 ServerApp] Jupyter Server 1.18.1 is running at:
   Mar 01 10:43:40 raspberrypi jupyter-server[19453]: [I 2023-03-01 10:43:40.009 ServerApp] http://localhost:8888/
   Mar 01 10:43:40 raspberrypi jupyter-server[19453]: [I 2023-03-01 10:43:40.010 ServerApp]  or http://127.0.0.1:8888/
   Mar 01 10:43:40 raspberrypi jupyter-server[19453]: [I 2023-03-01 10:43:40.010 ServerApp] Use Control-C to stop this server and shut down all ke

The above output shows that the service is running (``Active: active (running)``) and provides the
``STDOUT`` and ``STDERR`` streams from the service. If the service is not running, the ``STDOUT``
messages should provide a clue to what the problem might be.

.. _usage_debugging_jupyter:

Jupyter Lab Debugging
---------------------

For debugging when developing your own extensions for the project, the Jupyter environment provides a
useful debugging tool, shown next to the Kernel selection button in the top right of the Jupyter Lab
interface:

.. figure:: ../images/UserInterfaceJupyterDebugHighlight.png
   :align: center
   :scale: 50%
   :alt: Web app UI module structure

Clicking this button will enable the debugging tool, allowing you to set breakpoints in your code,
that will pause the execution of your code when the breakpoint is reached. This can be useful for
checking the values of variables, as your code is running, to make sure that they are what you
expect them to be. To include a breakpoint in your code, simply add the following line:

.. code-block:: python

   breakpoint()

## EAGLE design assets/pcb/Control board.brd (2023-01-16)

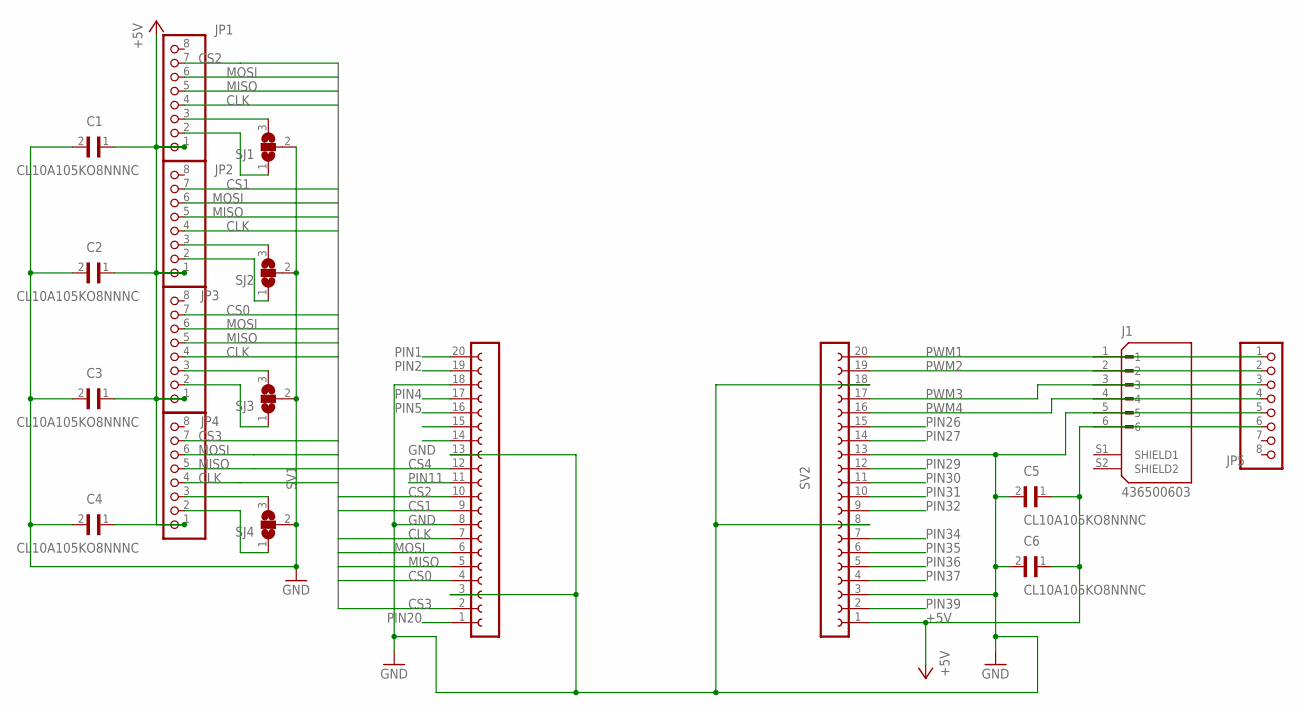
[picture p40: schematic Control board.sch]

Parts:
C1, C2, C3, C4, C5, C6: CL10A105KO8NNNC; CAPC1608X90N
J1: 436500603; MOLEX_436500603
JP1, JP2, JP3, JP4, JP5: PINHD-1X81X08/FE; HDRVR8W64P254_1X8_2159X200X810B
SJ1, SJ2, SJ3, SJ4: SJ2W; SJ_2
SV1, SV2: FE20-1; FE20

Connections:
+5V: C1.1, C2.1, C3.1, C4.1, C5.1, C6.1, J1.6, JP1.1, JP2.1, JP3.1, JP4.1, JP5.6, SV2.1
CLK: JP1.4, JP2.4, JP3.4, JP4.4, SV1.7
CS0: JP3.7, SV1.4
CS1: JP2.7, SV1.9
CS2: JP1.7, SV1.10
CS3: JP4.7, SV1.2
CS4: SV1.12
GND: C1.2, C2.2, C3.2, C4.2, C5.2, C6.2, J1.5, JP5.5, SJ1.2, SJ2.2, SJ3.2, SJ4.2, SV1.3, SV1.8, SV1.13, SV1.18, SV2.3, SV2.8, SV2.13, SV2.18
MISO: JP1.5, JP2.5, JP3.5, JP4.5, SV1.5
MOSI: JP1.6, JP2.6, JP3.6, JP4.6, SV1.6
unnamed: JP4.2, SJ4.1
unnamed: JP1.3, SJ1.3
unnamed: JP1.2, SJ1.1
unnamed: JP2.3, SJ2.3
unnamed: JP2.2, SJ2.1
unnamed: JP3.3, SJ3.3
unnamed: JP3.2, SJ3.1
unnamed: JP4.3, SJ4.3
PIN1: SV1.20
PIN2: SV1.19
PIN4: SV1.17
PIN5: SV1.16
PIN11: SV1.11
PIN20: SV1.1
PIN26: SV2.15
PIN27: SV2.14
PIN29: SV2.12
PIN30: SV2.11
PIN31: SV2.10
PIN32: SV2.9
PIN34: SV2.7
PIN35: SV2.6
PIN36: SV2.5
PIN37: SV2.4
PIN39: SV2.2
PWM1: J1.1, JP5.1, SV2.20
PWM2: J1.2, JP5.2, SV2.19
PWM3: J1.3, JP5.3, SV2.17
PWM4: J1.4, JP5.4, SV2.16

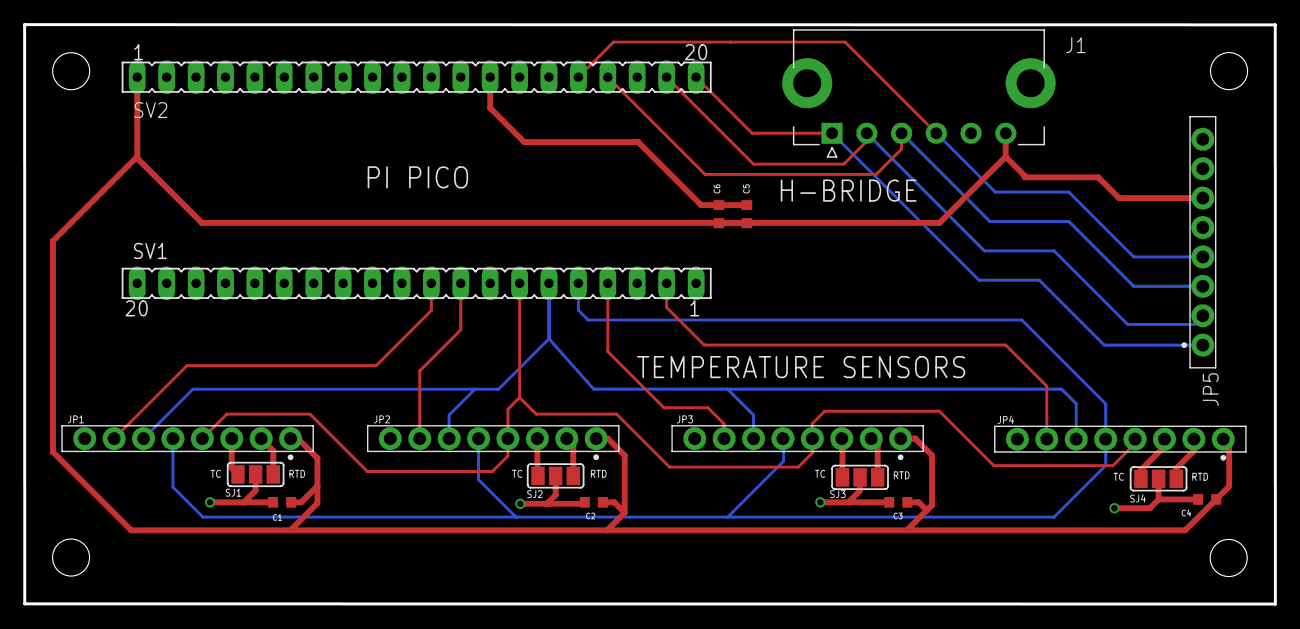
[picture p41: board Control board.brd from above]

Board: 2 copper layers, 108.0 x 50.0 mm, 18 parts (0 on the bottom side), 21 nets.

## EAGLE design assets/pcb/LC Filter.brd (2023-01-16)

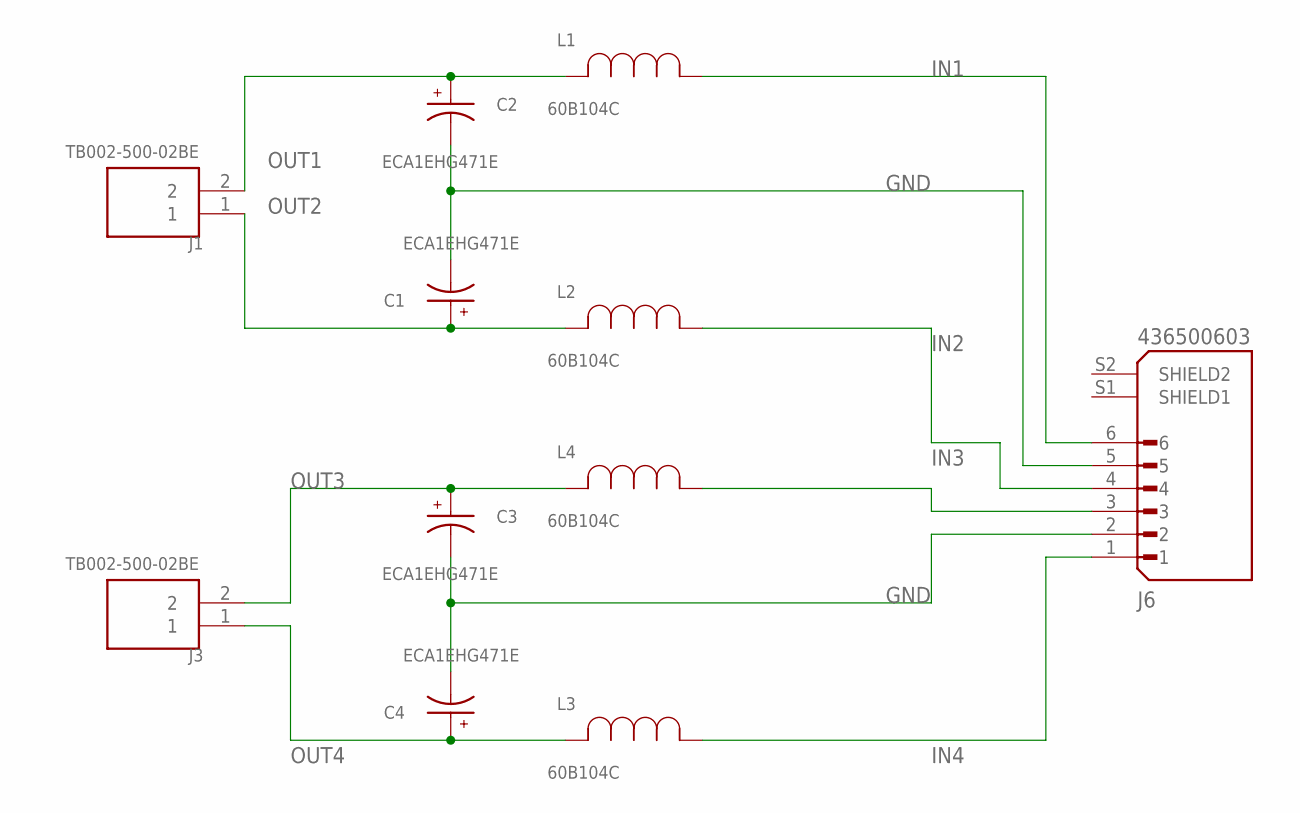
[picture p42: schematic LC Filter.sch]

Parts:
C1, C2, C3, C4: ECA1EHG471E; CAPPRD500W60D1000H1250
J1, J3: TB002-500-02BE; CUI_TB002-500-02BE
J6: 436500603; MOLEX_436500603
L1, L2, L3, L4: 60B104C; 6000B_SERIES_MUR

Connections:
GND: C1.N, C2.N, C3.N, C4.N, J6.2, J6.5
IN1: J6.6, L1.1
IN2: J6.4, L2.1
IN3: J6.3, L4.1
IN4: J6.1, L3.1
OUT1: C2.P, J1.2, L1.2
OUT2: C1.P, J1.1, L2.2
OUT3: C3.P, J3.2, L4.2
OUT4: C4.P, J3.1, L3.2

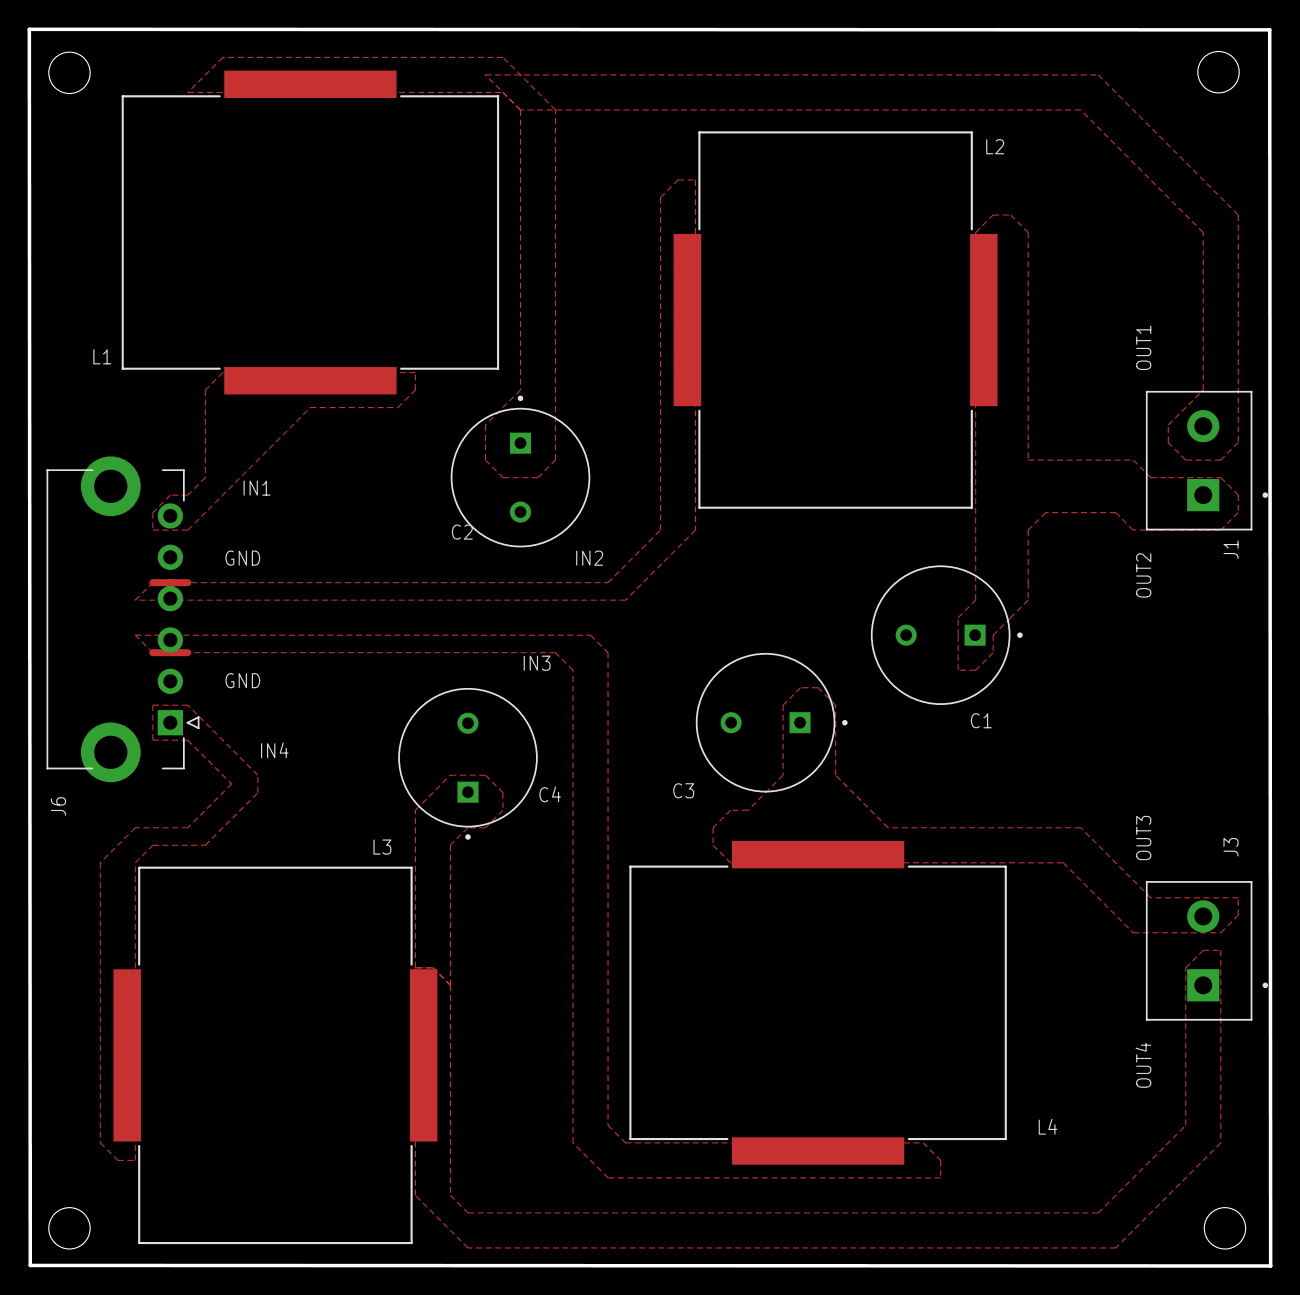
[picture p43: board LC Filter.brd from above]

Board: 2 copper layers, 90.0 x 89.7 mm, 11 parts (0 on the bottom side), 9 nets.

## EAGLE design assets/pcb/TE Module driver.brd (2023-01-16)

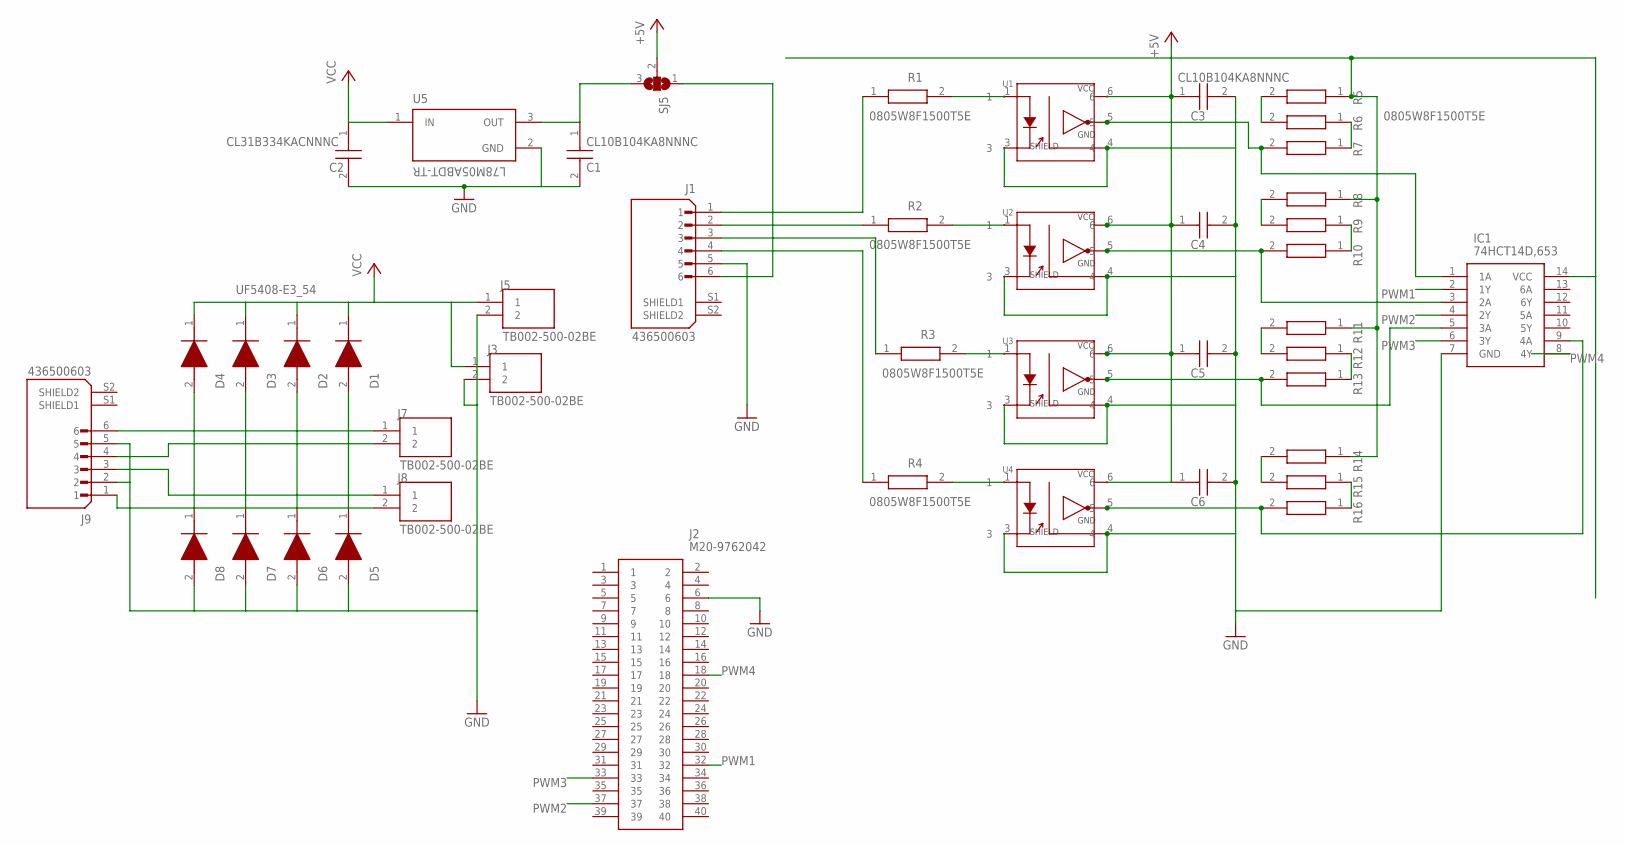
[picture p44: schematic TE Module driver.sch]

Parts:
C1, C3, C4, C5, C6: CL10B104KA8NNNC; CAPC1608X90N
C2: CL31B334KACNNNC; CAPC3216X140N
D1, D2, D3, D4, D5, D6, D7, D8: UF5408-E3_54; DIOAD2855W132L835D505
IC1: 74HCT14D,653; SOIC127P600X175-14N
J1, J9: 436500603; MOLEX_436500603
J2: M20-9762042; HDRV40W64P254_2X20_5080X508X83
J3, J5, J7, J8: TB002-500-02BE; CUI_TB002-500-02BE
R1, R2, R3, R4, R5, R6, R7, R8, R9, R10, R11, R12, R13, R14, R15, R16: 0805W8F1500T5E; RESC2013X65N
SJ5: SJ2W; SJ_2
U1, U2, U3, U4: TLP2362(TPL,E(T; 5PIN_SO6_TOS
U5: L78M05ABDT-TR; VREG_L78M05ABDT-TR

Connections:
+5V: C3.1, C4.1, C5.1, C6.1, IC1.14 (VCC), R5.1, R8.1, R11.1, R14.1, SJ5.2, U1.6, U2.6, U3.6, U4.6
GND: C1.2, C2.2, C3.2, C4.2, C5.2, C6.2, D5.2 (A), D6.2 (A), D7.2 (A), D8.2 (A), IC1.7 (GND), J1.5, J2.6, J3.2, J5.2, J9.2, J9.5, U1.3, U1.4, U2.3, U2.4, U3.3, U3.4, U4.3, U4.4, U5.2 (GND)
unnamed: J1.2, R2.1
unnamed: D4.2 (A), D8.1 (K), J7.1, J9.6
unnamed: D3.2 (A), D7.1 (K), J7.2, J9.4
unnamed: D2.2 (A), D6.1 (K), J8.1, J9.3
unnamed: D1.2 (A), D5.1 (K), J8.2, J9.1
unnamed: R2.2, U2.1
unnamed: R1.2, U1.1
unnamed: IC1.3 (2A), R10.2, U2.5
unnamed: IC1.5 (3A), R13.2, U3.5
unnamed: R3.2, U3.1
unnamed: R4.2, U4.1
unnamed: C1.1, SJ5.3, U5.3 (OUT)
unnamed: IC1.1 (1A), R7.2, U1.5
unnamed: R5.2, R6.2
unnamed: R6.1, R7.1
unnamed: J1.6, SJ5.1
unnamed: J1.1, R1.1
unnamed: J1.3, R3.1
unnamed: J1.4, R4.1
unnamed: R8.2, R9.2
unnamed: R9.1, R10.1
unnamed: R11.2, R12.2
unnamed: R12.1, R13.1
unnamed: IC1.9 (4A), R16.2, U4.5
unnamed: R14.2, R15.2
unnamed: R15.1, R16.1
PWM1: IC1.2 (1Y), J2.32
PWM2: IC1.4 (2Y), J2.37
PWM3: IC1.6 (3Y), J2.33
PWM4: IC1.8 (4Y), J2.18
VCC: C2.1, D1.1 (K), D2.1 (K), D3.1 (K), D4.1 (K), J3.1, J5.1, U5.1 (IN)

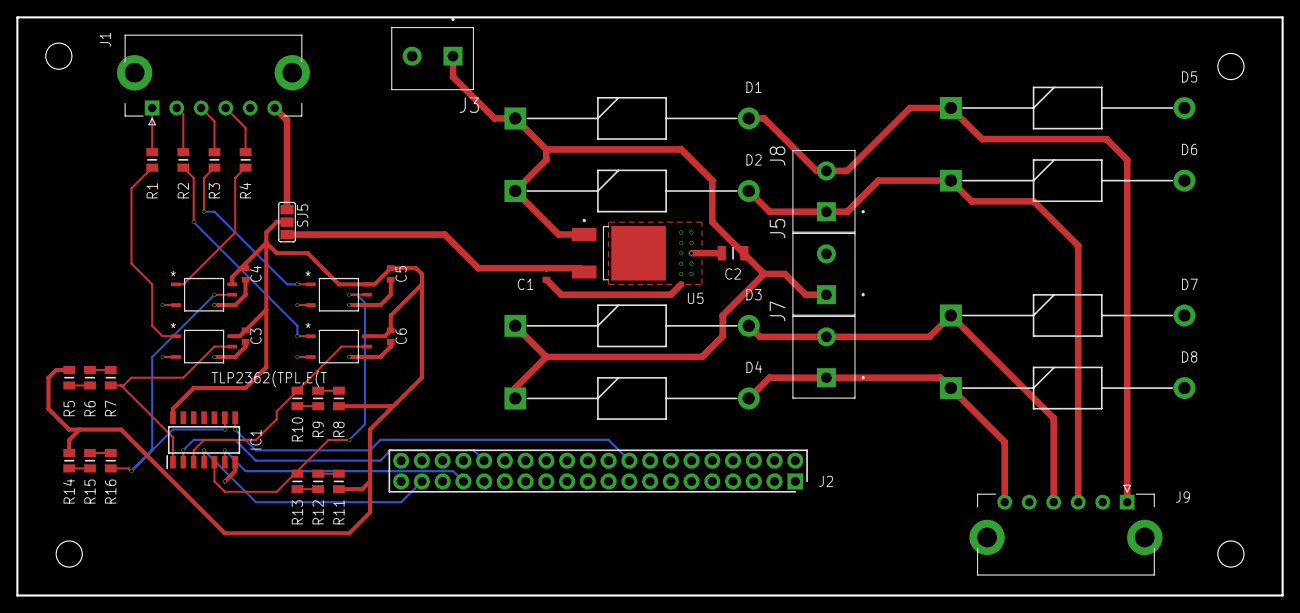
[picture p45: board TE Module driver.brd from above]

Board: 2 copper layers, 154.9 x 70.8 mm, 44 parts (0 on the bottom side), 33 nets.

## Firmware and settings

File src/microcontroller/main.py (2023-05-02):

"""
Main programme that is run when the microcontroller powers on.

Defines the :class:`Supervisor` class, which is responsible for:

* Collecting together the various component modules that make up the system,
  which are specified in the :attr:`components` attribute.
* Holding the system state, specified in the :attr:`config` attribute.
* Synchronising the system state with the python code running on the connected
  computer, using the :meth:`pull_config` method.
* Sending recorded sensors data to the computer, using the :meth:`push_data`
  method.
* Executing the main control loop, implemented by the :meth:`Supervisor.run` 
  method.

"""
import asyncio
import time

from log import Log
from client import SerialClient
from PID import PIDState
from sensor import TempSensor, TimeSensor, PIDSensor
from setup import *
from utils import ResponsiveDict


class Supervisor:
    """
    The Supervisor 
    
    """
    def __init__(self, serial_client, PID, log):
        
        self.components = [serial_client, PID, log]
        self.client = serial_client
    
        self.config = {
             'RUN': False,
             'MODE': False,
             'LOG': False,
             'TARGET': 23,
             'KP': 35.0,
             'KD': 2.0,
             'KI': 3.5,
             'INTERVAL':0.25
            }
        
    def pull_config(self):
        """
        
        """
        for msg in self.client.buf_in.copy():
            try:
                config = eval(msg.decode('utf-8'))
                for key,val in zip(config.keys(), config.values()):
                    for component in self.components:
                        if key in component.config.keys():
                            if component.config[key] != val:
                                component.config[key] = val
                    self.config[key] = val
                self.client.write(b'ACK:'+str(self.config).encode('utf-8')+b'\n')
                self.client.buf_in.remove(msg)
            except NameError as err:
                self.client.buf_in.remove(msg)
            except SyntaxError as err:
                self.client.buf_in.remove(msg)
        
    def push_data(self):
        # Message size scales as approximately 65 + (5+4+5)*(number of readings sent)
        bytesFree = self.client.buf_out_bytes_free
        if bytesFree > 160:
            num_request = (bytesFree -65) // 14
            data, n = self.log.read(num_request)
            message_string = b'DATA:' + str(data).encode('utf-8') + b'\n'
            message_len = len(message_string)
            self.client.buf_out[bytesFree-message_len:bytesFree] = message_string
            self.client.buf_out_bytes_free -= message_len
        

    def run(self):
        _ = [component.update() for component in self.components]
        self.pull_config()
        self.push_data()
        
    def wait(self, lastTimeStamp):
        while(time.monotonic_ns()-lastTimeStamp<self.config['INTERVAL']*1E9):
            time.sleep(0.001)
        return time.monotonic_ns()
            
thisPID = PIDState(max31865b,kp=7.0, ki=2.5, kd=0.1)

tempSensorA = TempSensor('TEMP', max31865a)
tempSensorB = TempSensor('TEMP', max31865b)
dTempSensor = TempSensor('DTEMP', max31856a, precision=2)
timeSensor = TimeSensor('TIME')
pidSensor = PIDSensor('PID', thisPID)

thisLog = Log(0.25, [ pidSensor, tempSensorA, tempSensorB, dTempSensor, timeSensor])

thisClient = SerialClient()

thisSupervisor = Supervisor(thisClient, thisPID, thisLog)
        
def main():
    lastTimeStamp = time.monotonic_ns()
    while True:
        thisSupervisor.run()
        lastTimeStamp = thisSupervisor.wait(lastTimeStamp)

main()

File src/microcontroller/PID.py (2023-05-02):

"""Defines the :class:`PIDState` class, which is responsible for controlling
and regulating the PWM output to the H-bridge, based on the system mode, target
temperature and heat rate.
"""
import setup
import time
#import asyncio
from utils import ResponsiveDict

class PIDState:
    """The :class:`PIDState` class is responsible for controlling and 
    regulating the PWM output from the microcontroller. used to control
    the power delivery to the heating element of the system.

    This is determined by the system mode, target temperature and heat rate,
    during a heating run, with a PID control loop used to calculate the
    appropriate PWM output.

    Parameters
    ----------
    
    :param sensor: The temperature sensor used for the PID control loop
    :type sensor: :class:`TempSensor`
    :param kp: The proportional gain of the PID control loop
    :type kp: float
    :param ki: The integral gain of the PID control loop
    :type ki: float
    :param kd: The derivative gain of the PID control loop
    :type kd: float
    :param Ts: The sampling period of the PID control loop
    :type Ts: float
    """

    # Attributes

    config = ResponsiveDict(
        {
            'RUN': False,       # PWM output enable
            'MODE': False,      # Ramp/Hold mode
            'TARGET': 23,       # Target heat rate / temperature
            'KP': 35.0,         # Proportional gain
            'KI':3.5,           # Integral gain
            'KD':2.0            # Derivative gain
        }
    )
    """Configuration dictionary for the PID controller. As a ResponsiveDict,
    whenever the value of any of the dictionary items in changed, a function
    will be called in response. See the `set_callback` lines in the `__init__`
    method.
    """

    #: Error
    e = 0.

    #: Output value
    u = 0.

    #: Change in output value
    delta_u = 0.

    
    def __init__(self, sensor, kp=1.0, ki=0., kd=0., sample_time=0.25):
        self._sensor = sensor
        self.config = ResponsiveDict(
            {
                'RUN': False,
                'MODE': False, 
                'TARGET': self.temp, 
                'KP': kp, 
                'KI':ki, 
                'KD':kd
                }
            )

        self.config.set_callback('MODE', lambda vals, args :
                             self.reset('MODE') if vals[0]!=vals[1] else None)
        # When 'MODE' value changes, call self.reset('MODE') if 
        # new value != old value
        self.config.set_callback('KP', lambda vals, args :
                             self.reset('KP') if vals[0]!=vals[1] else None)
        # When 'KP' value changes, call self.reset('MODE') if 
        # new value != old value
        self.config.set_callback('KD', lambda vals, args :
                             self.reset('KD') if vals[0]!=vals[1] else None)
        # When 'KD' value changes, call self.reset('MODE') if 
        # new value != old value
        self.config.set_callback('KI', lambda vals, args :
                             self.reset('KI') if vals[0]!=vals[1] else None)
        # When 'KI' value changes, call self.reset('MODE') if 
        # new value != old value

        ### Set initial values

        # Error values
        self.e = 0.
        self.e1 = 0.
        self.e2 = 0.

        # Output value
        self.u = 0.
        # Change in output value
        self.delta_u = 0.

        # Sample time
        self.Ts = sample_time

        # PID algorithm pre-factors
        self.k1 = kp + (ki*self.Ts) + kd/self.Ts
        self.k2 = -kp - 2*kd/self.Ts
        self.k3 = kd/self.Ts

        self.start_time = 0.
        self.current_time = 0.
        self.start_temperature = self.temp
        self.current_temperature = self.temp
        
    @property
    def temp(self):
        """Current temperature value measured by sensor

        :return: Current temperature value
        :rtype: float
        """
        return self._sensor.temperature
    
    def reset(self, trigger=None):
        """Reset PID controller values to defaults

        Can specify optional string `trigger`, to print which config
        value changed, for debugging
        """
        msg = 'Reset!'
        if trigger:
            msg += ' Due to {}'.format(trigger)
        print(msg)
        self.e = 0.
        self.e1 = 0.
        self.e2 = 0.
        self.delta_u = 0.
        self.u = 0.
        self.k1 = self.config['KP'] + self.config['KI']*self.Ts + max(self.config['KD'],0.001)/self.Ts
        self.k2 = -self.config['KP'] - 2*max(self.config['KD'],0.001)/self.Ts
        self.k3 = max(self.config['KD'],0.001)/self.Ts
        self.start_time = time.monotonic()
        self.current_time = time.monotonic()
        self.start_temperature = self.temp
        self.current_temperature = self.temp

        # Print values of Kp, Ki and Kd (useful for debugging)
        print(self.config['KP'], self.config['KI'], self.config['KD'])

    def update(self):
        """This function updates the frequency of the PWM output, as well as
        the direction pin, using the PID algorithm. 
        """
        # Update current temperature and time values
        self.current_temperature = self.temp
        self.current_time = time.monotonic()

        # Set e2 <= e1, e1 <= e
        self.e2 = self.e1
        self.e1 = self.e
    
        # For temperature ramp mode, calculate error as
        # e = start_temperature + (ramp_time * heat_rate) - current_temperature
        if self.config['MODE']:
            ramp_time = max((self.current_time - self.start_time), 0.1)
            heat_rate = self.config['TARGET']/60.
            self.e = self.start_temperature + (ramp_time * heat_rate) - \
                                self.current_temperature

        # For temperature hold mode, calculate error as
        # e = target_temp - current_temp
        else:
            self.e = self.config['TARGET'] - self.current_temperature

        # Calculate required change in output based on PID algorithm
        self.delta_u = self.k1*self.e + \
                       self.k2*self.e1 + \
                       self.k3*self.e2
        
        if self.config['RUN']:
            # If active, modify output
            self.u = self.u + self.delta_u
        else:
            # If idle, set output to 0
            self.u = 0

        # Print error value (useful for debugging)
        print('Error: {}'.format(self.e))

        # PID output limits, bounding output between +100% and -100%
        if (self.u > 100):
            self.u = 100.
        elif (self.u < -100):
            self.u = -100.
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

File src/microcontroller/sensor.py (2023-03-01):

"""
A wrapper class, used to provide a common interface to the various sensors and
values to log.
"""
import time
import PID

class Sensor:
    """ 
    An abstract wrapper class for objects with data that can be read from

    Can be subclassed to provide a common interface for different types of
    devices. The :meth:`read` method must therefore be overridden to provide
    a meaningful return value.
    """
    def __init__(self, name):
        self.name = name
        
    def read(self):
        """ Read current data value from :class:`Sensor` object

        :return: The current value measured by the sensor
        :rtype: None
        """
        return None
    
    def reset(self):
        return True
    
class TempSensor(Sensor):
    
    def __init__(self, name, device, precision=1):
        super().__init__(name)
        self.device = device
        self.precision = precision
        
    def read(self):
        return round(self.device.temperature, self.precision)
    
class TimeSensor(Sensor):
    
    def __init__(self, name):
        super().__init__(name)
        self.__startTime = None
        
    @property
    def time_ns(self):
        if self.__startTime:
            return time.monotonic_ns()-self.__startTime
        else:
            return 0.
        
    @property
    def time(self):
        if self.__startTime:
            return round((time.monotonic_ns() - self.__startTime) / 1e9, 3)
        else:
            return 0.
    
    def start(self):
        self.__startTime = time.monotonic_ns()
        return True
        
    def reset(self):
        self.__startTime = None
        return True
        
    def read(self):
        return self.time
    
class PIDSensor(Sensor):
    
    def __init__(self, name, PID):
        super().__init__(name)
        self.PID = PID
        
    def read(self):
        return self.PID.u

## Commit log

2022-08-10 Implementation of basic helper classes ResponsiveDict and ResponsiveList, as well as prototype implementation of class capturing behaviour/characteristics of a DTA run
2022-08-10 Setup script defining pin definitions and instantiation of library interface objects (such as Adafruit MAX31865 library).
2022-08-10 Removed reset functionality from PIDSensor class.
    [sensor.py]
2022-08-10 Moved basic setup definitions/initialisations to setup.py script.
    Moved resposibility for controllinng runtime program flow inside Supervisor class.
2022-08-10 Added graphics displaying profile of configured DTA programme, as well as change in temperature
2022-08-10 Modified update() function of PIDState to allow for PID control of heating rate, as well as temperature, depending on mode.
2022-08-10 Changed details of connection teardown/start. Fixed bug with data_received function; added pickle serialisation of data objects, for transport over socket
2022-08-10 Module holding and maintaining global variables/configuration for webapp.py
    Also modifies configuration based on DTA programme and current readings.
2022-08-10 Added button control for up/down key presses, useful for setting programme configuration on touchscreen
2022-08-10 Validation test data for temperature/heat PID control (in pickled binary form)
2022-08-19 Added reset button and functionality, as well as programme heating rate profile
2022-08-19 Added support for thermocouple measurements, modified PID error calculation for heating mode, enabled PID configuration from webapp
    [PID.py, client.py, log.py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]
2022-08-24 Minor refactoring of how PID values are handled
2022-08-24 Added page for saving recorded data.
    Updated requests so that new readings are appended to current series, rather than downloading entire series each request.
    Moved statements associated with reset button in UI to main() function (lines 120-130) of this module.
2022-08-24 Added configuration page for adjusting DTA system parameters such as PID parameters, as well as time interval between subsequent recordings
2022-08-24 Added page view for selecting mountable drives under /media/pi/ (i.e usb disk drives) and filenames, for exporting saved data
2022-08-24 Renamed 'config.py' to 'programme.py', so that 'config.py' can be used for third page (adjusting PID params + interval)
2022-08-24 IPython notebook for exploring timing of subroutines on Pico
2022-09-17 Added EAGLE PCB files
    [Control board.brd, Control board.sch, LC Filter.brd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]
2023-01-16 Replaced global variables with class attributes in other modules, added additional sensors
2023-01-16 Included refactor changes relating to previous commit, added unicode symbols for better text labelling, added legend to graph, made line colors more visually distinct, changed limits for right axis t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
2023-01-16 Added configuration options for filter frequency, cold junction disable, baudrate and auto-conversion to class constructor
2023-02-25 Rework project tree structure
    [Control board.brd, Control board.sch, LC Filter.brd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]
2023-02-25 Tidy up restructure
    [Control board.brd, Control board.sch, LC Filter.brd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]
2023-03-01 Added docs for utils.py, setup.py and PID.py in microcontroller code

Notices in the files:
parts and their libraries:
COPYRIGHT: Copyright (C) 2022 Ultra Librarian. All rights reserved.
